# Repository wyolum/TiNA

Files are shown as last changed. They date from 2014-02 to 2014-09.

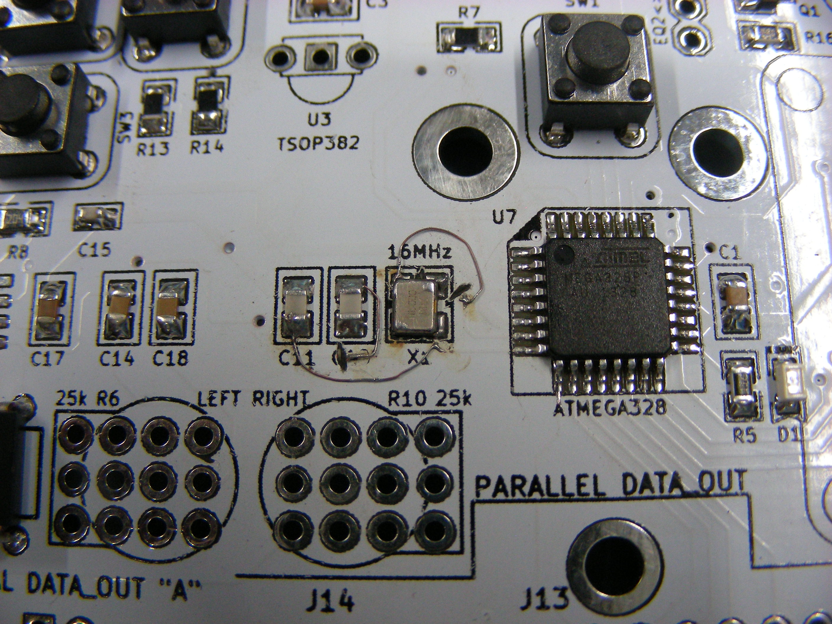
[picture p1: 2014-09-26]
KiCAD/TiNA_Images/DSCN0223.JPG

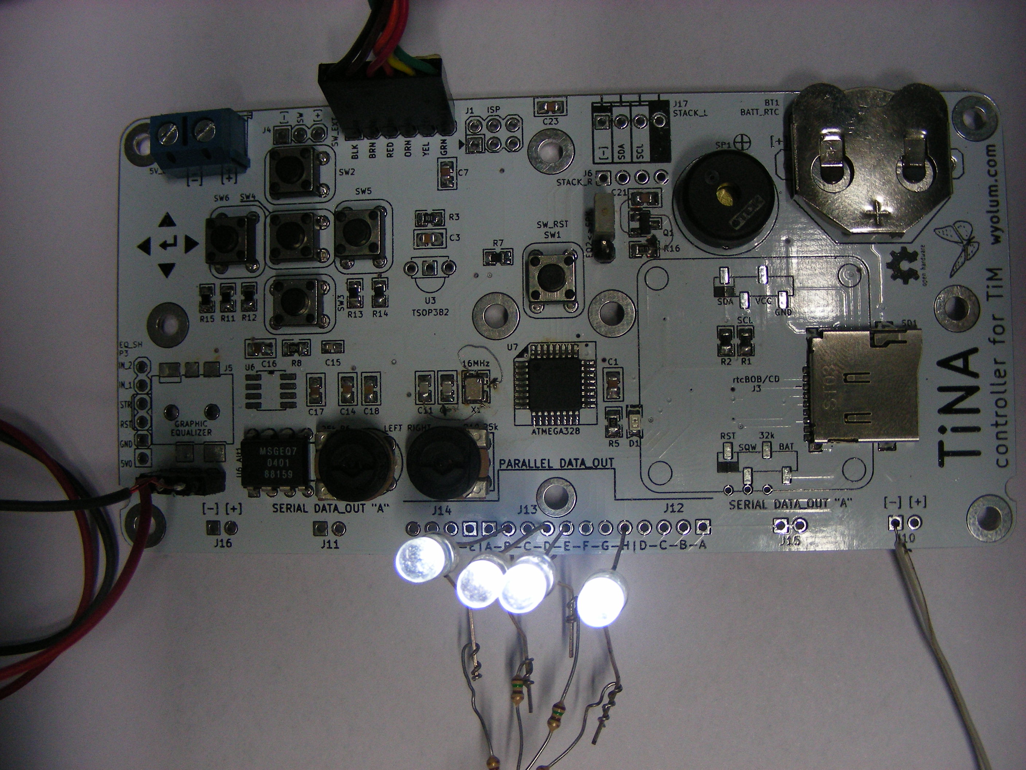
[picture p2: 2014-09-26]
KiCAD/TiNA_Images/DSCN0236.JPG

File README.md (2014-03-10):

TiNA
====

Standalone controller for TIM (The Intelligent Matrix)

To install arduino libraries:
1. download and unzip (or git clone) the files to a local directory
   for example, my this is /home/justin/code/TiNA
2. set your arduino sketchbook path to the arduino subdirectory of your install path by either 
    a. editing your ~/.arduino/preferences.txt (the sketchbook.path variable)
    b. selecting from the "File->Preferences" drop down menu item
    for example, my sketchbook path is /home/justin/code/TiNA/arduino
3. start or restart the Arduino IDE

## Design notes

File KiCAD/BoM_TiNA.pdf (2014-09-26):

TOTAL | 32.26
ref | QTY | DESCRIPTION | value | PACKAGE | Manufacturer | Mfr. P/N | Vendor | Vendor P/N | RATEAMOUNT
BT1 | 1 | | 3003 | 3003K-ND | 0.59 | 0.59
-- | 1 | CR2032 | CR2032 | 0.28 | 0.28
| 6 | 0.1µF | C0805C104K3RACTU | | 0.10 | 0.60
C2 C5 | 2 | 1.0µF | CL21B105KOFNNNE | | 0.10 | 0.20
C3 | 1 | 220nF | CL21B224KBFSFNE | | 0.10 | 0.10
C10 C11 | 2 | 22pF | C0805C220KBRACTU | | 0.08 | 0.17
C24 C25 C26 | 3 | 22uF | C3225X7R1C226M250AC | | 0.84 | 2.52
D1 | 1 | | | | 0.22 | 0.22
Q1 | 1 | MMBT2222 | MMBT2222A | MMBT2222AFSCT-ND | 0.18 | 0.18
| 9 | 10k | RMCF0805JT10K0 | RMCF0805JT10K0CT-ND | 0.03 | 0.27
R3 | 1 | 100E | RMCF0805JT100R | RMCF0805JT100RCT-ND | 0.03 | 0.03
R5 R16 | 2 | 1k5 | RMCF0805JT1K50 | RMCF0805JT1K50CT-ND | 0.03 | 0.06
SD1 | 1 | ? | ? | 0.00
SP1 | 1 | | PS1240P02BT | | 0.73 | 0.73
6 | 1825910-7 | 0.10 | 0.60
U1 | 1 | SOT23-3 | 0.44 | 0.44
U2 | 1 | TXB0104D | TXB0104DR | 1.69 | 1.69

HOLDER BATTERY COIN
20MM DIA THM | BATT_RTC | Coin, 20.0mm | Keystone Electronics | Digikey (http://www.digikey.com/scripts/DkSearch/dksus.dll?x=0&y=0&lang=en&KeyWords=3003K-ND&cur=USD)

BATTERY LITHIUM COIN
3V 20MM | Coin Battery | Panasonic - BSG | | Digikey (http://www.digikey.com/product-detail/en/CR2032/P189-ND/31939?cur=USD) | P189-ND

C1 C7 C9 C21
C22 C23

CAP CER 0.1UF 25V 10%
X7R 0805

0805 (2012
Metric) | Kemet | DigiKey (http://www.digikey.com/product-detail/en/C0805C104K3RACTU/399-1168-1-ND/411443) | 399-1168-1-ND

CAP CER 1UF 16V 10%
X7R 0805

0805 (2012
Metric)
| | Samsung Electro-
| | Mechanics America, Inc | | DigiKey (http://www.digikey.com/product-detail/en/CL21B105KOFNNNE/1276-1026-1-ND/3889112) | 1276-1026-1-ND

CAP CER 0.22UF 50V 10%
X7R 0805

0805 (2012
Metric)
| | Samsung Electro-
| | Mechanics America, Inc | | DigiKey (http://www.digikey.com/product-detail/en/CL21B224KBFSFNE/1276-2948-1-ND/3891034) | 1276-2948-1-ND

CAP CER 22PF 630V 10%
X7R 0805

0805 (2012
Metric) | Kemet | DigiKey (http://www.digikey.com/product-detail/en/C0805C220KBRACTU/399-5568-2-ND/2033869) | 399-5568-2-ND

CAP CER 22UF 16V 20%
X7R 1210

1210 (3225
Metric) | TDK Corporation | DigiKey (http://www.digikey.com/product-detail/en/C3225X7R1C226M250AC/445-3955-1-ND/1944442) | 445-3955-1-ND
LED, indicator, BLINK | LED | 2-SMD, J-Lead | OSRAM Opto
| | Semiconductors Inc | LG M67K-H1J2-24-Z | DigiKey (http://www.digikey.com/product-detail/en/LG%20M67K-H1J2-24-Z/475-2730-1-ND/1938897?cur=USD) | 475-2730-1-ND

TRANSISTOR GP NPN
AMP SOT-23 | SOT-23-3 | Fairchild Semiconductor | DigiKey (http://www.digikey.com/product-detail/en/MMBT2222A/MMBT2222AFSCT-ND/458969)

R1 R2 R7 R9 R11
R12 R13 R14
R15

RES 10K OHM 1/8W 5%
0805

0805 (2012
Metric) | Stackpole Electronics Inc | DigiKey (http://www.digikey.com/product-detail/en/RMCF0805JT10K0/RMCF0805JT10K0CT-ND/1942577)

RES 100 OHM 1/8W 5%
0805

0805 (2012
Metric) | Stackpole Electronics Inc | DigiKey (http://www.digikey.com/product-detail/en/RMCF0805JT100R/RMCF0805JT100RCT-ND/1942539)

RES 1.5K OHM 1/8W 5%
0805

0805 (2012
Metric) | Stackpole Electronics Inc | DigiKey (http://www.digikey.com/product-detail/en/RMCF0805JT1K50/RMCF0805JT1K50CT-ND/1942560)
Micro SD Card Socket | SD_CARD_MICR
| O | | | seeed | ST-SD-006A

BUZZER PIEZO 4KHZ
12.2MM PC MNT | Speaker

Circular -
12.20mm Dia x
6.50mm H
| | TDK Corporation | | DigiKey (http://www.digikey.com/product-detail/en/PS1240P02BT/445-2525-1-ND/935930) | 445-2525-1-ND

SW1 SW2 SW3
SW4 SW5 SW6
SWITCH TACTILE SPST- NO 0.05A 12V | SW_RST SW_UP
| SW_DN SW_OK
| SW_LT SW_RT

6.00mm x
6.00mm | TE Connectivity | DigiKey (http://www.digikey.com/product-detail/en/1825910-7/450-1804-ND/1731414) | 450-1804-ND
IC REG LDO 3.3V 0.25A | LDO 3V3 | Microchip Technology | MCP1700T-3302E/TT | DigiKey (http://www.digikey.com/product-search/en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) | MCP1700T3302ETTCT-
| | | | | ND
(or U1_Alt1) | (or SOT-89-3) | (or MCP1700T-
| | | 3302E/MB) | | (or
| | | | | MCP1700T3302EMBCT-
| | | | | ND)

IC VOLT-LEVEL
TRANSLATOR 14-SOIC

14-SOIC (0.154",
| | 3.90mm Width) Texas Instruments | | DigiKey (http://www.digikey.com/product-detail/en/TXB0104DR/296-21928-1-ND/1629281) | 296-21928-1-ND

U4 | 1 | DS3231N | DS3231S# | | 8.82 | 8.82
U7 | 1 | ATMEGA328P | ATMEGA328P-AU | ATMEGA328P-AU-ND | 3.12 | 3.12
X1 | 1 | 16MHz | | SER3628CT-ND | 0.63 | 0.63
J1 | 1 | PREC003DAAN-RC | 0.25 | 0.25
1 | PREC040SAAN-RC | 0.51 | 0.51
J8 | 1 | OSTTA024163 | 0.42 | 0.42
J5 | 1 | CP1-3515SJPICT-ND | 1.45 | 1.45
U3 | 1 | TSOP382 | | TSOP38238 | | 0.91 | 0.91
U6 | 1 | MSGEQ7 | SO8 | MSGEQ7 | MSGEQ7 | 4.95 | 4.95
C14 C18 | 2 | 10nF | CL21B103JBANNNC | 0.11 | 0.22
C15 | 1 | 33pF | 0603YC330JAT2A | 0.18 | 0.18
C16 C17 | 2 | 0.1µF | C0805C104K3RACTU | 0.10 | 0.20
R6 R10 | 2 | 25k | 262UR253B | 262UR253B-ND | 0.69 | 1.38
IC RTC W/TCXO 16-SOIC | 16-SOIC (0.295",
| 7.50mm Width) | Maxim Integrated
Products | DigiKey (http://goo.gl/gg9GS) | DS3231S#-ND

IC MCU 8BIT 32KB FLASH
32TQFP | 32-TQFP | Atmel | DigiKey (http://www.digikey.com/product-detail/en/ATMEGA328P-AU/ATMEGA328P-AU-ND/1832260)
CRYSTAL 16MHZ 9PF SMD | 4-SMD, No Lead
(DFN, LCC) | EPSON | TSX-3225 16.0000MF09Z-
AC3 | DigiKey (http://www.digikey.com/product-detail/en/TSX-3225%2016.0000MF09Z-AC3/SER3628CT-ND/1802879)

DO NOT
POPULATE
CONN HEADER .100"
DUAL STR 6POS | ISP | Dual row, 0.1” | Sullins Connector
Solutions | DigiKey (http://www.digikey.com/product-detail/en/PREC003DAAN-RC/S2012EC-03-ND/2774891) | S2012EC-03-ND

J2 J4 J6 J10 J11
J12 J13 J14 J15
J16 J17 J18

CONN HEADER .100"
SNGL STR 40POS

PWR_1 SER_1
PAR_1 PAR_2
PAR_3 SER_2
PWR_2 STACK_R
EqIn_EXT FTDI
SW_EXT
STACK_L

Single row, 0.1” Sullins Connector
Solutions | DigiKey (http://www.digikey.com/product-detail/en/PREC040SAAN-RC/S1012EC-40-ND/2774814) | S1012EC-40-ND

TERM BLOCK 5.08MM

VERT 2POS PCB | 5V_EXT | Through Hole,
0.2” | On Shore Technology Inc | DigiKey (http://www.digikey.com/product-detail/en/OSTTA024163/ED2580-ND/614529) | ED2580-ND

CONN JACK STEREO
5POS 3.5MM SMD

JACK_3.5MM_5P
IN

3.50mm (0.141",
1/8", Mini Plug) -
Headphone
CUI Inc | SJ1-3515-SMT-TR-PI | DigiKey (http://www.digikey.com/product-detail/en/SJ1-3515-SMT-TR-PI/CP1-3515SJPICT-ND/2296003)

IC IR RCVR MOD 38KHZ

DOME AXIAL | Side View | Vishay Semiconductor
| Opto Division | DigiKey (http://www.digikey.com/product-detail/en/TSOP38238/751-1227-ND/1681362) | 751-1227-ND

IC seven band graphic
equalizer | MSI | Sparkfun (https://www.sparkfun.com/products/10468)
(or U6_Alt1) | DIP-8
CAP CER 10000PF 50V
5% X7R 0805
0805 (2012 Metric) | Samsung Electro-
| Mechanics America, Inc | DigiKey (http://www.digikey.com/product-detail/en/CL21B103JBANNNC/1276-1245-1-ND/3889331) | 1276-1245-1-ND

CAP CER 33PF 16V 5%
X7R 0603

0603 (1608
Metric) | AVX Corporation | DigiKey (http://www.digikey.com/product-detail/en/0603YC330JAT2A/478-6211-1-ND/2391410) | 478-6211-1-ND

CAP CER 0.1UF 25V 10%
X7R 0805

0805 (2012
Metric) | Kemet | DigiKey (http://www.digikey.com/product-detail/en/C0805C104K3RACTU/399-1168-1-ND/411443) | 399-1168-1-ND

TRIMMER 25K OHM
0.15W TH

Square - 0.370" L
x 0.368" W x
0.213" H
(9.40mm x
9.35mm x
5.40mm)
CTS Electrocomponents | DigiKey (http://www.digikey.com/product-detail/en/262UR253B/262UR253B-ND/3063)

R8 | 1 | 200k | RMCF0805JT200K | RMCF0805JT200KCT-ND | 0.03 | 0.03
P2 P3 | 1 | | PREC040SAAN-RC | | 0.51 | 0.51

10.00

C4 | 1 | 10uF | CL31B106KOHNNNE | | 0.29 | 0.29
C6 C13 | 2 | 0.1µF | C0805C104K3RACTU | | 0.10 | 0.20
C8 | 1 | 3.3nF X7R | C0805C332K5RACTU | | 0.10 | 0.10
C12 | 1 | 22uF | C3225X7R1C226M250AC | | 0.84 | 0.84
C19 C20 | 2 | 100uF | UWT1V101MCL1GS | | 0.48 | 0.96
D2 | 1 | | GBU4M-BP | GBU4M-BPMS-ND | 0.88 | 0.88
J7 J9 | 2 | | OSTTA024163 | | 0.42 | 0.84
L1 | 1 | 2.2uH | XFL4020-222MEB | 994-XFL4020-222MEB | 2.13 | 2.13
R4 | 1 | 100k | RMCF0805JT100K | RMCF0805JT100KCT-ND | 0.03 | 0.03
U5 | 1 | TPS62133 | TPS62133RGTT | | 3.73 | 3.73

RES 200K OHM 1/8W 5%
0805

0805 (2012
Metric) | Stackpole Electronics Inc | DigiKey (http://www.digikey.com/product-detail/en/RMCF0805JT200K/RMCF0805JT200KCT-ND/1942595)

CONN HEADER .100"
SNGL STR 10POS

SPK<>EQ2

EQ_SH | Single row, 0.1” Sullins Connector
Solutions | DigiKey (http://www.digikey.com/product-detail/en/PREC040SAAN-RC/S1012EC-40-ND/2774814) | S1012EC-40-ND
POWER SUPPLY | TOTAL

CAP CER 10UF 16V 10%
X7R 1206

1206 (3216
Metric)

Samsung Electro-
Mechanics America, Inc | DigiKey (http://www.digikey.com/product-detail/en/CL31B106KOHNNNE/1276-1082-1-ND/3889168) | 1276-1082-1-ND

CAP CER 0.1UF 25V 10%
X7R 0805

0805 (2012
Metric) | Kemet | DigiKey (http://www.digikey.com/product-detail/en/C0805C104K3RACTU/399-1168-1-ND/411443) | 399-1168-1-ND

CAP CER 3300PF 50V
10% X7R 0805

0805 (2012
Metric) | Kemet | DigiKey (http://www.digikey.com/product-detail/en/C0805C332K5RACTU/399-1153-1-ND/411428) | 399-1153-1-ND

CAP CER 22UF 16V 20%
X7R 1210

1210 (3225
Metric) | TDK Corporation | DigiKey (http://www.digikey.com/product-detail/en/C3225X7R1C226M250AC/445-3955-1-ND/1944442) | 445-3955-1-ND

CAP ALUM 100UF 35V
20% SMD

Radial, Can -
SMD | Nichicon | DigiKey (http://www.digikey.com/product-detail/en/UWT1V101MCL1GS/493-2203-1-ND/590178) | 493-2203-1-ND

RECT BRIDGE GPP 4A
1000V GBU | Bridge | Through Hole | Micro Commercial Co | DigiKey (http://www.digikey.com/product-detail/en/GBU4M-BP/GBU4M-BPMS-ND/1140594)

TERM BLOCK 5.08MM

VERT 2POS PCB | V_IN 5V_EXT | Through Hole,
0.2” | On Shore Technology Inc | DigiKey (http://www.digikey.com/product-detail/en/OSTTA024163/ED2580-ND/614529) | ED2580-ND

Power Inductor 2.2 uH 20
% 8 A

4.3 mm W x 4.3
mm L x 2.1 mm H | Coilcraft | Mouser (http://in.mouser.com/ProductDetail/Coilcraft/XFL4020-222MEB/?qs=VJjuEbE9QBO2bwonVBK1EA==)

RES 100K OHM 1/8W 5%
0805

0805 (2012
Metric) | Stackpole Electronics Inc | DigiKey (http://www.digikey.com/product-detail/en/RMCF0805JT100K/RMCF0805JT100KCT-ND/1942592)

IC REG BUCK SYNC 5V 3A
16QFN

16-VFQFN
Exposed Pad | Texas Instruments | DigiKey (http://www.digikey.com/product-detail/en/TPS62133RGTT/296-30225-1-ND/2982139) | 296-30225-1-ND

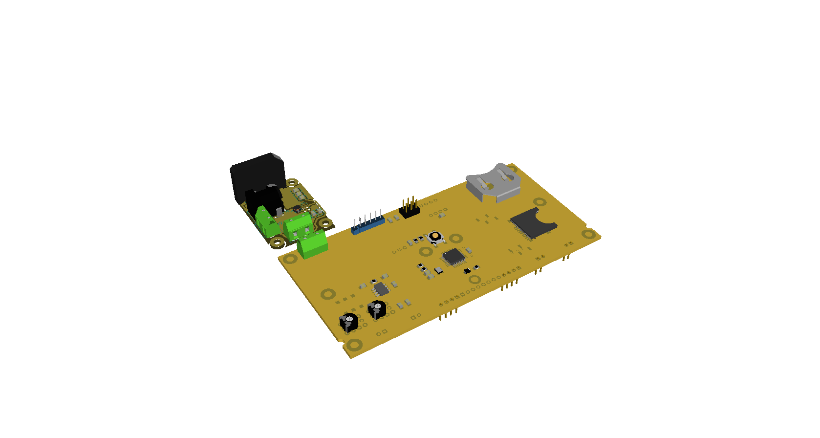
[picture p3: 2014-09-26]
KiCAD/TiNA_Images/TiNA_01.png

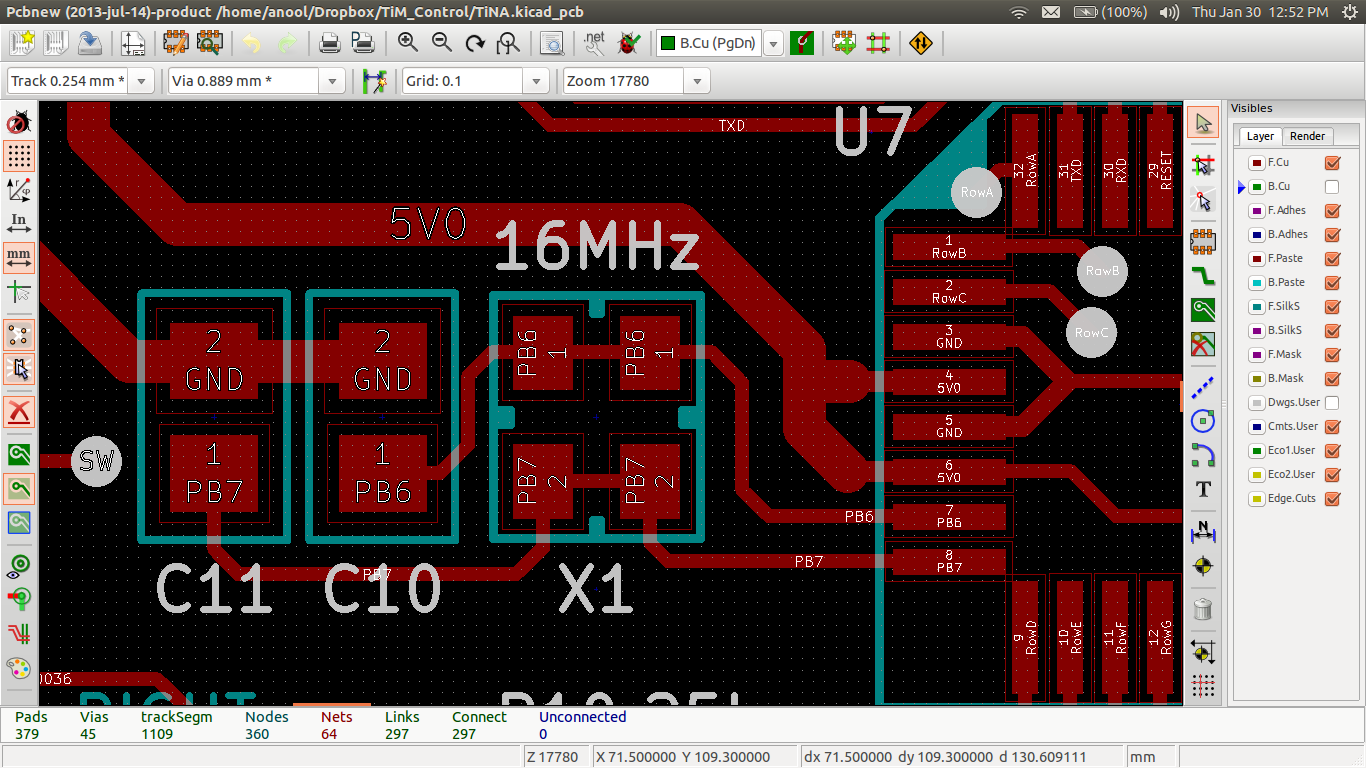
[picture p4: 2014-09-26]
KiCAD/TiNA_Images/TiNA_Mod_BEFORE.png

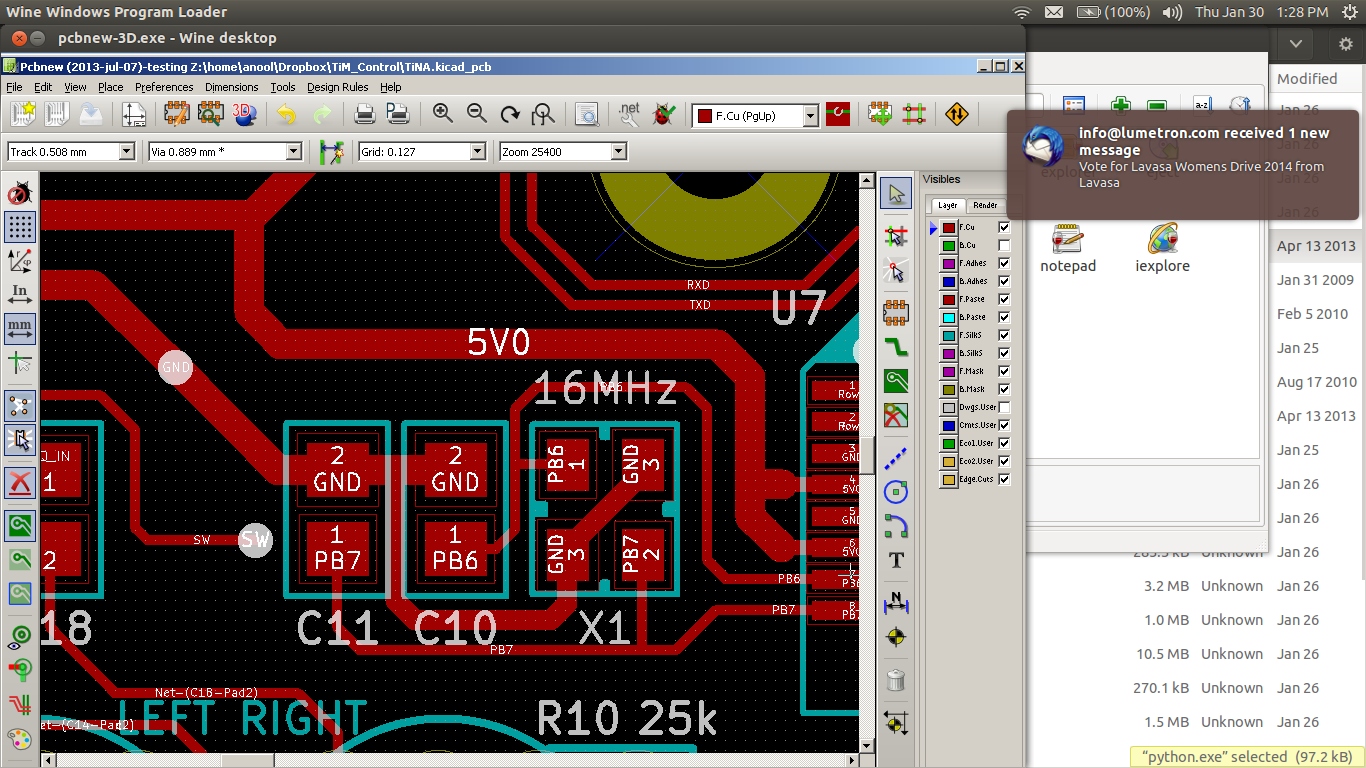
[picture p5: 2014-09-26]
KiCAD/TiNA_Images/Screenshot from 2014-01-30 13:28:08.png

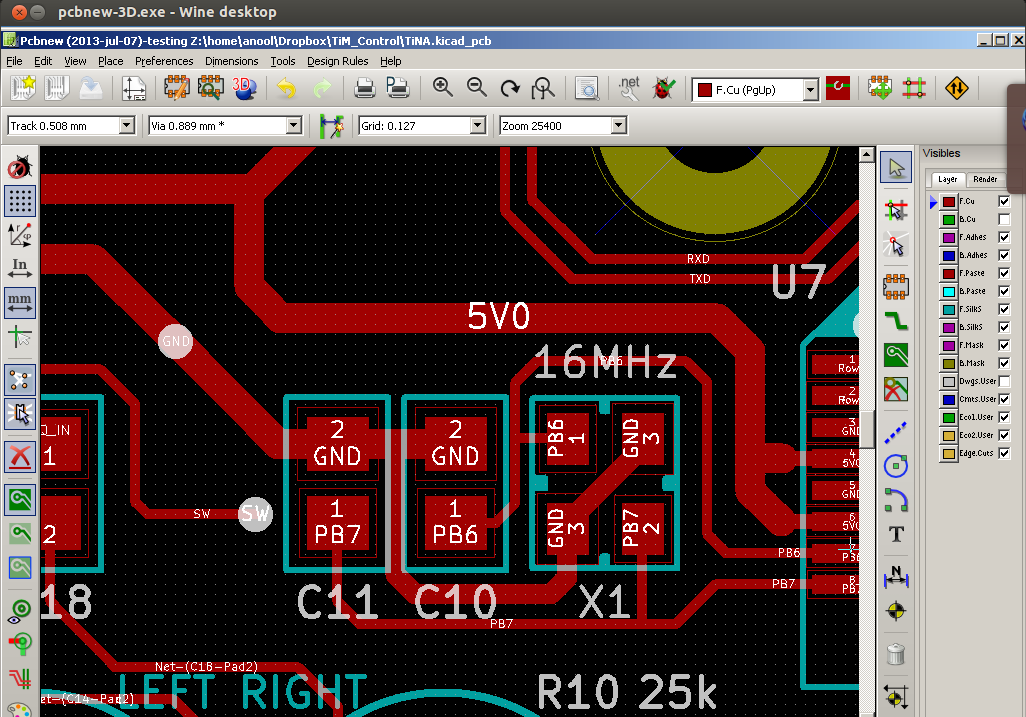
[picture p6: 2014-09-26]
KiCAD/TiNA_Images/TiNA_Mod_AFTER.png

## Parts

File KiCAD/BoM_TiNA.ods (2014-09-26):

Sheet: Final_BoM
 |  |  |  |  |  |  |  |  | TOTAL | 29.66
ref | QTY | DESCRIPTION | value | PACKAGE | Manufacturer | Mfr. P/N | Vendor | Vendor P/N | RATE | AMOUNT
BT1 | 1 | HOLDER BATTERY COIN 20MM DIA THM | BATT_RTC | Coin, 20.0mm | Keystone Electronics | 3003 | Digikey (http://www.digikey.com/scripts/DkSearch/dksus.dll?x=0&y=0&lang=en&KeyWords=3003K-ND&cur=USD) | 3003K-ND | 0.59 | 0.59
-- | 1 | BATTERY LITHIUM COIN 3V 20MM | Coin Battery | CR2032 | Panasonic - BSG | CR2032 | Digikey (http://www.digikey.com/product-detail/en/CR2032/P189-ND/31939?cur=USD) | P189-ND | 0.28 | 0.28
C1 C7 C9 C21 C22 C23 | 6 | CAP CER 0.1UF 25V 10% X7R 0805 | 0.1µF | 0805 (2012 Metric) | Kemet | C0805C104K3RACTU | DigiKey (http://www.digikey.com/product-detail/en/C0805C104K3RACTU/399-1168-1-ND/411443) | 399-1168-1-ND | 0.10 | 0.60
C2 C5 | 2 | CAP CER 1UF 16V 10% X7R 0805 | 1.0µF | 0805 (2012 Metric) | Samsung Electro-Mechanics America, Inc | CL21B105KOFNNNE | DigiKey (http://www.digikey.com/product-detail/en/CL21B105KOFNNNE/1276-1026-1-ND/3889112) | 1276-1026-1-ND | 0.10 | 0.20
C3 | 1 | CAP CER 0.22UF 50V 10% X7R 0805 | 220nF | 0805 (2012 Metric) | Samsung Electro-Mechanics America, Inc | CL21B224KBFSFNE | DigiKey (http://www.digikey.com/product-detail/en/CL21B224KBFSFNE/1276-2948-1-ND/3891034) | 1276-2948-1-ND | 0.10 | 0.10
C10 C11 | 2 | CAP CER 22PF 630V 10% X7R 0805 | 22pF | 0805 (2012 Metric) | Kemet | C0805C220KBRACTU | DigiKey (http://www.digikey.com/product-detail/en/C0805C220KBRACTU/399-5568-2-ND/2033869) | 399-5568-2-ND | 0.08 | 0.17
C14 C18 | 2 | CAP CER 10000PF 50V 5% X7R 0805 | 10nF | 0805 (2012 Metric) | Samsung Electro-Mechanics America, Inc | CL21B103JBANNNC | DigiKey (http://www.digikey.com/product-detail/en/CL21B103JBANNNC/1276-1245-1-ND/3889331) | 1276-1245-1-ND | 0.11 | 0.22
C15 | 1 | CAP CER 33PF 16V 5% X7R 0603 | 33pF | 0603 (1608 Metric) | AVX Corporation | 0603YC330JAT2A | DigiKey (http://www.digikey.com/product-detail/en/0603YC330JAT2A/478-6211-1-ND/2391410) | 478-6211-1-ND | 0.18 | 0.18
C16 C17 | 2 | CAP CER 0.1UF 25V 10% X7R 0805 | 0.1µF | 0805 (2012 Metric) | Kemet | C0805C104K3RACTU | DigiKey (http://www.digikey.com/product-detail/en/C0805C104K3RACTU/399-1168-1-ND/411443) | 399-1168-1-ND | 0.10 | 0.20
C24 C25 C26 | 3 | CAP CER 22UF 16V 20% X7R 1210 | 22uF | 1210 (3225 Metric) | TDK Corporation | C3225X7R1C226M250AC | DigiKey (http://www.digikey.com/product-detail/en/C3225X7R1C226M250AC/445-3955-1-ND/1944442) | 445-3955-1-ND | 0.84 | 2.52
D1 | 1 | LED, indicator, BLINK | LED | 2-SMD, J-Lead | OSRAM Opto Semiconductors Inc | LG M67K-H1J2-24-Z | DigiKey (http://www.digikey.com/product-detail/en/LG%20M67K-H1J2-24-Z/475-2730-1-ND/1938897?cur=USD) | 475-2730-1-ND | 0.22 | 0.22
J5 | 1 | CONN JACK STEREO 5POS 3.5MM SMD | JACK_3.5MM_5PIN | 3.50mm (0.141", 1/8", Mini Plug) - Headphone | CUI Inc | SJ1-3515-SMT-TR-PI | DigiKey (http://www.digikey.com/product-detail/en/SJ1-3515-SMT-TR-PI/CP1-3515SJPICT-ND/2296003) | CP1-3515SJPICT-ND | 1.45 | 1.45
Q1 | 1 | TRANSISTOR GP NPN AMP SOT-23 | MMBT2222 | SOT-23-3 | Fairchild Semiconductor | MMBT2222A | DigiKey (http://www.digikey.com/product-detail/en/MMBT2222A/MMBT2222AFSCT-ND/458969) | MMBT2222AFSCT-ND | 0.18 | 0.18
R1 R2 R7 R9 R11 R12 R13 R14 R15 | 9 | RES 10K OHM 1/8W 5% 0805 | 10k | 0805 (2012 Metric) | Stackpole Electronics Inc | RMCF0805JT10K0 | DigiKey (http://www.digikey.com/product-detail/en/RMCF0805JT10K0/RMCF0805JT10K0CT-ND/1942577) | RMCF0805JT10K0CT-ND | 0.03 | 0.27
R3 | 1 | RES 100 OHM 1/8W 5% 0805 | 100E | 0805 (2012 Metric) | Stackpole Electronics Inc | RMCF0805JT100R | DigiKey (http://www.digikey.com/product-detail/en/RMCF0805JT100R/RMCF0805JT100RCT-ND/1942539) | RMCF0805JT100RCT-ND | 0.03 | 0.03
R5 R16 | 2 | RES 1.5K OHM 1/8W 5% 0805 | 1k5 | 0805 (2012 Metric) | Stackpole Electronics Inc | RMCF0805JT1K50 | DigiKey (http://www.digikey.com/product-detail/en/RMCF0805JT1K50/RMCF0805JT1K50CT-ND/1942560) | RMCF0805JT1K50CT-ND | 0.03 | 0.06
R6 R10 | 2 | TRIMMER 25K OHM 0.15W TH | 25k | Square - 0.370" L x 0.368" W x 0.213" H (9.40mm x 9.35mm x 5.40mm) | CTS Electrocomponents | 262UR253B | DigiKey (http://www.digikey.com/product-detail/en/262UR253B/262UR253B-ND/3063) | 262UR253B-ND | 0.69 | 1.38
R8 | 1 | RES 200K OHM 1/8W 5% 0805 | 200k | 0805 (2012 Metric) | Stackpole Electronics Inc | RMCF0805JT200K | DigiKey (http://www.digikey.com/product-detail/en/RMCF0805JT200K/RMCF0805JT200KCT-ND/1942595) | RMCF0805JT200KCT-ND | 0.03 | 0.03
SD1 | 1 | Micro SD Card Socket | SD_CARD_MICRO |  | ? | ? | seeed | ST-SD-006A |  | 0.00
SP1 | 1 | BUZZER PIEZO 4KHZ 12.2MM PC MNT | Speaker | Circular - 12.20mm Dia x 6.50mm H | TDK Corporation | PS1240P02BT | DigiKey (http://www.digikey.com/product-detail/en/PS1240P02BT/445-2525-1-ND/935930) | 445-2525-1-ND | 0.73 | 0.73
SW1 SW2 SW3 SW4 SW5 SW6 | 6 | SWITCH TACTILE SPST-NO 0.05A 12V | SW_RST SW_UP SW_DN SW_OK SW_LT SW_RT | 6.00mm x 6.00mm | TE Connectivity | 1825910-7 | DigiKey (http://www.digikey.com/product-detail/en/1825910-7/450-1804-ND/1731414) | 450-1804-ND | 0.10 | 0.60
U1 | 1 | IC REG LDO 3.3V 0.25A | LDO 3V3 | SOT23-3 | Microchip Technology | MCP1700T-3302E/TT | DigiKey (http://www.digikey.com/product-search/en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) | MCP1700T3302ETTCT-ND | 0.44 | 0.44
(or U1_Alt1) |  |  |  | (or SOT-89-3) |  | (or MCP1700T-3302E/MB) |  | (or MCP1700T3302EMBCT-ND)
U2 | 1 | IC VOLT-LEVEL TRANSLATOR 14-SOIC | TXB0104D | 14-SOIC (0.154", 3.90mm Width) | Texas Instruments | TXB0104DR | DigiKey (http://www.digikey.com/product-detail/en/TXB0104DR/296-21928-1-ND/1629281) | 296-21928-1-ND | 1.69 | 1.69
U4 | 1 | IC RTC W/TCXO 16-SOIC | DS3231N | 16-SOIC (0.295", 7.50mm Width) | Maxim Integrated Products | DS3231S# | DigiKey (http://goo.gl/gg9GS) | DS3231S#-ND | 8.82 | 8.82
U6 | 1 | IC seven band graphic equalizer | MSGEQ7 | SO8 | MSI | MSGEQ7 | Sparkfun (https://www.sparkfun.com/products/10468) | MSGEQ7 | 4.95 | 4.95
(or U6_Alt1) |  |  |  | DIP-8
U7 | 1 | IC MCU 8BIT 32KB FLASH 32TQFP | ATMEGA328P | 32-TQFP | Atmel | ATMEGA328P-AU | DigiKey (http://www.digikey.com/product-detail/en/ATMEGA328P-AU/ATMEGA328P-AU-ND/1832260) | ATMEGA328P-AU-ND | 3.12 | 3.12
X1 | 1 | CRYSTAL 16MHZ 9PF SMD | 16MHz | 4-SMD, No Lead (DFN, LCC) | EPSON | TSX-3225 16.0000MF09Z-AC3 | DigiKey (http://www.digikey.com/product-detail/en/TSX-3225%2016.0000MF09Z-AC3/SER3628CT-ND/1802879) | SER3628CT-ND | 0.63 | 0.63
POWER SUPPLY |  |  |  |  |  |  |  |  | TOTAL | 10.00
C4 | 1 | CAP CER 10UF 16V 10% X7R 1206 | 10uF | 1206 (3216 Metric) | Samsung Electro-Mechanics America, Inc | CL31B106KOHNNNE | DigiKey (http://www.digikey.com/product-detail/en/CL31B106KOHNNNE/1276-1082-1-ND/3889168) | 1276-1082-1-ND | 0.29 | 0.29
C6 C13 | 2 | CAP CER 0.1UF 25V 10% X7R 0805 | 0.1µF | 0805 (2012 Metric) | Kemet | C0805C104K3RACTU | DigiKey (http://www.digikey.com/product-detail/en/C0805C104K3RACTU/399-1168-1-ND/411443) | 399-1168-1-ND | 0.10 | 0.20
C8 | 1 | CAP CER 3300PF 50V 10% X7R 0805 | 3.3nF X7R | 0805 (2012 Metric) | Kemet | C0805C332K5RACTU | DigiKey (http://www.digikey.com/product-detail/en/C0805C332K5RACTU/399-1153-1-ND/411428) | 399-1153-1-ND | 0.10 | 0.10
C12 | 1 | CAP CER 22UF 16V 20% X7R 1210 | 22uF | 1210 (3225 Metric) | TDK Corporation | C3225X7R1C226M250AC | DigiKey (http://www.digikey.com/product-detail/en/C3225X7R1C226M250AC/445-3955-1-ND/1944442) | 445-3955-1-ND | 0.84 | 0.84
C19 C20 | 2 | CAP ALUM 100UF 35V 20% SMD | 100uF | Radial, Can - SMD | Nichicon | UWT1V101MCL1GS | DigiKey (http://www.digikey.com/product-detail/en/UWT1V101MCL1GS/493-2203-1-ND/590178) | 493-2203-1-ND | 0.48 | 0.96
D2 | 1 | RECT BRIDGE GPP 4A 1000V GBU | Bridge | Through Hole | Micro Commercial Co | GBU4M-BP | DigiKey (http://www.digikey.com/product-detail/en/GBU4M-BP/GBU4M-BPMS-ND/1140594) | GBU4M-BPMS-ND | 0.88 | 0.88
J7 J9 | 2 | TERM BLOCK 5.08MM VERT 2POS PCB | V_IN 5V_EXT | Through Hole, 0.2” | On Shore Technology Inc | OSTTA024163 | DigiKey (http://www.digikey.com/product-detail/en/OSTTA024163/ED2580-ND/614529) | ED2580-ND | 0.42 | 0.84
L1 | 1 | Power Inductor 2.2 uH 20 % 8 A | 2.2uH | 4.3 mm W x 4.3 mm L x 2.1 mm H | Coilcraft | XFL4020-222MEB | Mouser (http://in.mouser.com/ProductDetail/Coilcraft/XFL4020-222MEB/?qs=VJjuEbE9QBO2bwonVBK1EA==) | 994-XFL4020-222MEB | 2.13 | 2.13
R4 | 1 | RES 100K OHM 1/8W 5% 0805 | 100k | 0805 (2012 Metric) | Stackpole Electronics Inc | RMCF0805JT100K | DigiKey (http://www.digikey.com/product-detail/en/RMCF0805JT100K/RMCF0805JT100KCT-ND/1942592) | RMCF0805JT100KCT-ND | 0.03 | 0.03
U5 | 1 | IC REG BUCK SYNC 5V 3A 16QFN | TPS62133 | 16-VFQFN Exposed Pad | Texas Instruments | TPS62133RGTT | DigiKey (http://www.digikey.com/product-detail/en/TPS62133RGTT/296-30225-1-ND/2982139) | 296-30225-1-ND | 3.73 | 3.73
DO NOT POPULATE |  | (PLEASE ADD AS KIT PARTS)
J1 | 1 | CONN HEADER .100" DUAL STR 6POS | ISP | Dual row, 0.1” | Sullins Connector Solutions | PREC003DAAN-RC | DigiKey (http://www.digikey.com/product-detail/en/PREC003DAAN-RC/S2012EC-03-ND/2774891) | S2012EC-03-ND | 0.25 | 0.25
J2 J4 J6 J10 J11 J12 J13 J14 J15 J16 J17 J18 | 1 | CONN HEADER .100" SNGL STR 40POS | PWR_1 SER_1 PAR_1 PAR_2 PAR_3 SER_2 PWR_2 STACK_R EqIn_EXT FTDI SW_EXT STACK_L | Single row, 0.1” | Sullins Connector Solutions | PREC040SAAN-RC | DigiKey (http://www.digikey.com/product-detail/en/PREC040SAAN-RC/S1012EC-40-ND/2774814) | S1012EC-40-ND | 0.51 | 0.51
J8 | 1 | TERM BLOCK 5.08MM VERT 2POS PCB | 5V_EXT | Through Hole, 0.2” | On Shore Technology Inc | OSTTA024163 | DigiKey (http://www.digikey.com/product-detail/en/OSTTA024163/ED2580-ND/614529) | ED2580-ND | 0.42 | 0.42
U3 | 1 | IC IR RCVR MOD 38KHZ DOME AXIAL | TSOP382 | Side View | Vishay Semiconductor Opto Division | TSOP38238 | DigiKey (http://www.digikey.com/product-detail/en/TSOP38238/751-1227-ND/1681362) | 751-1227-ND | 0.91 | 0.91
P2 P3 | 1 | CONN HEADER .100" SNGL STR 10POS | SPK<>EQ2 EQ_SH | Single row, 0.1” | Sullins Connector Solutions | PREC040SAAN-RC | DigiKey (http://www.digikey.com/product-detail/en/PREC040SAAN-RC/S1012EC-40-ND/2774814) | S1012EC-40-ND | 0.51 | 0.51

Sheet: BoM_SCH
Designator | Designation | Quantity | Package
BT1 | BATT_RTC | 1 | CR2032
C1 C7 C9 C21 C22 C23 | 100nF | 6 | c_0805
C10 C11 | 22pF | 2 | c_0805
C24 C25 C26 | 22uF X7R | 3 | c_1210
C2 C5 | 1uF | 2 | c_0805
C3 | 220nF | 1 | c_0805
D1 | LED | 1 | d_0805
Q1 | MMBT2222 | 1 | SOT23-3
R1 R2 R7 R9 R11 R12 R13 R14 R15 | 10k | 9 | r_0805
R3 | 100E | 1 | r_0805
R5 R16 | 1k5 | 2 | r_0805
SD1 | SD_CARD_MICRO | 1 | SD_Micro_seeed
SP1 | SPEAKER | 1 | Speaker_2
SW1 | SW_RST | 1 | SW-PB
SW2 | SW_UP | 1 | SW-PB
SW3 | SW_DN | 1 | SW-PB
SW4 | SW_OK | 1 | SW-PB
SW5 | SW_LT | 1 | SW-PB
SW6 | SW_RT | 1 | SW-PB
U1 | MCP1700T-3V3 SOT23-3 | 1 | SOT23-3
U1_Alt1 | MCP1700T-3V3 SOT89 | 1 | SOT89
U2 | TXB0104D | 1 | TXB0104D
U4 | DS3231N | 1 | DS3231
U7 | ATMEGA328 | 1 | TQFP32
X1 | 16MHz | 1 | Xtal_SMD2
DNP
B2 B3 B15 | I/O | 3 | I/O
J1 | ISP | 1 | ISP
J2 | FTDI | 1 | PIN_ARRAY-6X1
J3 | rtcBOB/CD | 1 | rtcBOB
J4 | SW_EXT | 1 | PIN_ARRAY_3x1
J5 | JACK_3.5MM_5PIN | 1 | Jack_3.5mm_SJ1-3513
J6 | STACK_L | 1 | STACK-L
J8 | 5V_EXT | 1 | bornier2
J10 | PWR_1 | 1 | pin_strip_2
J11 | SER_1 | 1 | pin_strip_2
J12 | PAR_1 | 1 | PIN_ARRAY_4x1
J13 | PAR_2 | 1 | SIL-8
J14 | PAR_3 | 1 | PIN_ARRAY_4x1
J15 | SER_2 | 1 | pin_strip_2
J16 | PWR_2 | 1 | pin_strip_2
J17 | STACK_R | 1 | STACK-R
J18 | EqIn_EXT | 1 | PIN_ARRAY_3x1
P1 | V_IN | 1 | JACK_ALIM
SC1 SC2 SC3 SC4 SC5 SC6 SC7 SC8 SC9 SC10 SC11 SC12 | SCREW | 12 | vite_3mm
U3 | TSOP382 | 1 | TSOP382
P2 | SPK<>EQ2 | 1 | PIN_ARRAY_3x1
P3 | EQ_SH | 1 | PIN_ARRAY-6X1
U6 | MSGEQ7 | 1 | SO8E
U6_Alt1 | MSGEQ7_DIP | 1 | DIP-8__300
R6 R10 | 25k | 2 | Pot-Var2
R8 | 200k | 1 | r_0805
C14 C18 | 10nF | 2 | c_0805
C15 | 33pF | 1 | c_0603
C16 C17 | 100nF | 2 | c_0805
POWER SUPPLY
C4 | 10uF X7R | 1 | c_1206
C6 C13 | 100nF | 2 | c_0805
C8 | 3.3nF | 1 | c_0805
C12 | 22uF X7R | 1 | c_1210
C19 C20 | 100uF | 2 | C_ELCO_SMD
D2 | BRIDGE | 1 | Bridge
J7 | V_IN | 1 | bornier2
J9 | 5V_EXT | 1 | bornier2
L1 | 2u2H,3.0A | 1 | Inductor_SMD3
R4 | 100k | 1 | r_0805
U5 | TPS62133 | 1 | TPS62132

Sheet: BoM_PCB
Designator | Designation | Quantity | Package
BT1 | BATT_RTC | 1 | CR2032
C1 C7 C9 C21 C22 C23 | 100nF | 6 | c_0805
C10 C11 | 22pF | 2 | c_0805
C24 C26 C25 | 22uF X7R | 3 | c_1210
C2 C5 | 1uF | 2 | c_0805
C3 | 220nF | 1 | c_0805
D1 | LED | 1 | d_0805
Q1 | MMBT2222 | 1 | SOT23-3
R9 R7 R2 R1 R11 R12 R13 R14 R15 | 10k | 9 | r_0805
R3 | 100E | 1 | r_0805
R5 R16 | 1k5 | 2 | r_0805
SD1 | SD_CARD_MICRO | 1 | SD_Micro_seeed
SP1 | SPEAKER | 1 | Speaker_2
SW1 | SW_RST | 1 | SW-PB
SW2 | SW_UP | 1 | SW-PB
SW3 | SW_DN | 1 | SW-PB
SW4 | SW_OK | 1 | SW-PB
SW5 | SW_LT | 1 | SW-PB
SW6 | SW_RT | 1 | SW-PB
U1 | MCP1700T-3V3 SOT23-3 | 1 | SOT23-3
U1_Alt1 | MCP1700T-3V3 SOT89 | 1 | SOT89
U2 | TXB0104D | 1 | TXB0104D
U4 | DS3231N | 1 | DS3231
U7 | ATMEGA328 | 1 | TQFP32
X1 | 16MHz | 1 | Xtal_SMD2
DNP
B15 B3 B2 | I/O | 3 | I/O
J1 | ISP | 1 | ISP
J2 | FTDI | 1 | PIN_ARRAY-6X1
J3 | rtcBOB/CD | 1 | rtcBOB
J4 | SW_EXT | 1 | PIN_ARRAY_3x1
J5 | JACK_3.5MM_5PIN | 1 | Jack_3.5mm_SJ1-3513
J6 | STACK_L | 1 | STACK-L
J8 | 5V_EXT | 1 | bornier2
J10 | PWR_1 | 1 | pin_strip_2
J11 | SER_1 | 1 | pin_strip_2
J12 | PAR_1 | 1 | PIN_ARRAY_4x1
J13 | PAR_2 | 1 | SIL-8
J14 | PAR_3 | 1 | PIN_ARRAY_4x1
J15 | SER_2 | 1 | pin_strip_2
J16 | PWR_2 | 1 | pin_strip_2
J17 | STACK_R | 1 | STACK-R
J18 | EqIn_EXT | 1 | PIN_ARRAY_3x1
P1 | V_IN | 1 | JACK_ALIM
SC9 SC6 SC7 SC5 SC8 SC2 SC3 SC1 SC4 SC12 SC11 SC10 | SCREW | 12 | vite_3mm
U3 | TSOP382 | 1 | TSOP382
U6 | MSGEQ7 | 1 | SO8E
U6_Alt1 | MSGEQ7_DIP | 1 | DIP-8__300
R8 | 200k | 1 | r_0805
R6 R10 | 25k | 2 | Pot-Var2
C14 C18 | 10nF | 2 | c_0805
C15 | 33pF | 1 | c_0603
C1 C7 C9 C21 C22 C23 | 100nF | 2 | c_0805
P2 | SPK<>EQ2 | 1 | PIN_ARRAY_3x1
P3 | EQ_SH | 1 | PIN_ARRAY-6X1
POWER SUPPLY
C4 | 10uF X7R | 1 | c_1206
C6 C13 | 100nF | 2 | c_0805
C8 | 3.3nF | 1 | c_0805
C12 | 22uF X7R | 1 | c_1210
C20 C19 | 100uF | 2 | C_ELCO_SMD
D2 | BRIDGE | 1 | Bridge
J7 | V_IN | 1 | bornier2
J9 | 5V_EXT | 1 | bornier2
L1 | 2u2H, 3.0A | 1 | Inductor_SMD3
R4 | 100k | 1 | r_0805
U5 | TPS62133 | 1 | TPS62132

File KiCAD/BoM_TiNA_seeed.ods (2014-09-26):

Electronic Engineering BOM List
Product Name : TINA, WyoLum
Version：V1.0
Issue Date：19/Dec/2013
Item No. (序号) | Reference Des (上件位置) | Qty (用量) | Catalog (分类） | Part_Description (规格描述) | Part_Value （元件值） | Part_Package （元件封装） | Manufacturers Name (使用厂牌名称) | Manufacturers Part No. (使用厂牌型号) | Distributors Name （供应商名称） | Distributors Part No. (供貨商型号) | Unit Price （单价） | Price Break To Use （价格分段的购买量） | Notes/Remark （备注）
Example（填写范例）
1 | BT1 | 1 | OTHER | HOLDER BATTERY COIN 20MM DIA THM | BATT_RTC | Coin, 20.0mm | Keystone Electronics | 3003 | Digikey (http://www.digikey.com/scripts/DkSearch/dksus.dll?x=0&y=0&lang=en&KeyWords=3003K-ND&cur=USD) | 3003K-ND
2 | -- | 1 | OTHER | BATTERY LITHIUM COIN 3V 20MM | Coin Battery | CR2032 | Panasonic - BSG | CR2032 | Digikey (http://www.digikey.com/product-detail/en/CR2032/P189-ND/31939?cur=USD) | P189-ND
3 | C1 C7 C9 C21 C22 C23 | 6 | Capacitor | CAP CER 0.1UF 25V 10% X7R 0805 | 0.1µF | 0805 (2012 Metric) | Kemet | C0805C104K3RACTU | DigiKey (http://www.digikey.com/product-detail/en/C0805C104K3RACTU/399-1168-1-ND/411443) | 399-1168-1-ND
4 | C2 C5 | 2 | Capacitor | CAP CER 1UF 16V 10% X7R 0805 | 1.0µF | 0805 (2012 Metric) | Samsung Electro-Mechanics America, Inc | CL21B105KOFNNNE | DigiKey (http://www.digikey.com/product-detail/en/CL21B105KOFNNNE/1276-1026-1-ND/3889112) | 1276-1026-1-ND
5 | C3 | 1 | Capacitor | CAP CER 0.22UF 50V 10% X7R 0805 | 220nF | 0805 (2012 Metric) | Samsung Electro-Mechanics America, Inc | CL21B224KBFSFNE | DigiKey (http://www.digikey.com/product-detail/en/CL21B224KBFSFNE/1276-2948-1-ND/3891034) | 1276-2948-1-ND
6 | C10 C11 | 2 | Capacitor | CAP CER 22PF 630V 10% X7R 0805 | 22pF | 0805 (2012 Metric) | Kemet | C0805C220KBRACTU | DigiKey (http://www.digikey.com/product-detail/en/C0805C220KBRACTU/399-5568-2-ND/2033869) | 399-5568-2-ND
7 | C14 C18 | 2 | Capacitor | CAP CER 10000PF 50V 5% X7R 0805 | 10nF | 0805 (2012 Metric) | Samsung Electro-Mechanics America, Inc | CL21B103JBANNNC | DigiKey (http://www.digikey.com/product-detail/en/CL21B103JBANNNC/1276-1245-1-ND/3889331) | 1276-1245-1-ND
8 | C15 | 1 | Capacitor | CAP CER 33PF 16V 5% X7R 0603 | 33pF | 0603 (1608 Metric) | AVX Corporation | 0603YC330JAT2A | DigiKey (http://www.digikey.com/product-detail/en/0603YC330JAT2A/478-6211-1-ND/2391410) | 478-6211-1-ND
9 | C16 C17 | 2 | Capacitor | CAP CER 0.1UF 25V 10% X7R 0805 | 0.1µF | 0805 (2012 Metric) | Kemet | C0805C104K3RACTU | DigiKey (http://www.digikey.com/product-detail/en/C0805C104K3RACTU/399-1168-1-ND/411443) | 399-1168-1-ND
10 | C24 C25 C26 | 3 | Capacitor | CAP CER 22UF 16V 20% X7R 1210 | 22uF | 1210 (3225 Metric) | TDK Corporation | C3225X7R1C226M250AC | DigiKey (http://www.digikey.com/product-detail/en/C3225X7R1C226M250AC/445-3955-1-ND/1944442) | 445-3955-1-ND
11 | D1 | 1 | Diode | LED, indicator, BLINK | LED | 2-SMD, J-Lead | OSRAM Opto Semiconductors Inc | LG M67K-H1J2-24-Z | DigiKey (http://www.digikey.com/product-detail/en/LG%20M67K-H1J2-24-Z/475-2730-1-ND/1938897?cur=USD) | 475-2730-1-ND
12 | J5 | 1 | Connector | CONN JACK STEREO 5POS 3.5MM SMD | JACK_3.5MM_5PIN | 3.50mm (0.141", 1/8", Mini Plug) - Headphone | CUI Inc | SJ1-3515-SMT-TR-PI | DigiKey (http://www.digikey.com/product-detail/en/SJ1-3515-SMT-TR-PI/CP1-3515SJPICT-ND/2296003) | CP1-3515SJPICT-ND
13 | Q1 | 1 | Transistor | TRANSISTOR GP NPN AMP SOT-23 | MMBT2222 | SOT-23-3 | Fairchild Semiconductor | MMBT2222A | DigiKey (http://www.digikey.com/product-detail/en/MMBT2222A/MMBT2222AFSCT-ND/458969) | MMBT2222AFSCT-ND
14 | R1 R2 R7 R9 R11 R12 R13 R14 R15 | 9 | Resister | RES 10K OHM 1/8W 5% 0805 | 10k | 0805 (2012 Metric) | Stackpole Electronics Inc | RMCF0805JT10K0 | DigiKey (http://www.digikey.com/product-detail/en/RMCF0805JT10K0/RMCF0805JT10K0CT-ND/1942577) | RMCF0805JT10K0CT-ND
15 | R3 | 1 | Resister | RES 100 OHM 1/8W 5% 0805 | 100E | 0805 (2012 Metric) | Stackpole Electronics Inc | RMCF0805JT100R | DigiKey (http://www.digikey.com/product-detail/en/RMCF0805JT100R/RMCF0805JT100RCT-ND/1942539) | RMCF0805JT100RCT-ND
16 | R5 R16 | 2 | Resister | RES 1.5K OHM 1/8W 5% 0805 | 1k5 | 0805 (2012 Metric) | Stackpole Electronics Inc | RMCF0805JT1K50 | DigiKey (http://www.digikey.com/product-detail/en/RMCF0805JT1K50/RMCF0805JT1K50CT-ND/1942560) | RMCF0805JT1K50CT-ND
17 | R6 R10 | 2 | Resister | TRIMMER 25K OHM 0.15W TH | 25k | Square - 0.370" L x 0.368" W x 0.213" H (9.40mm x 9.35mm x 5.40mm) | CTS Electrocomponents | 262UR253B | DigiKey (http://www.digikey.com/product-detail/en/262UR253B/262UR253B-ND/3063) | 262UR253B-ND
18 | R8 | 1 | Resister | RES 200K OHM 1/8W 5% 0805 | 200k | 0805 (2012 Metric) | Stackpole Electronics Inc | RMCF0805JT200K | DigiKey (http://www.digikey.com/product-detail/en/RMCF0805JT200K/RMCF0805JT200KCT-ND/1942595) | RMCF0805JT200KCT-ND
19 | SD1 | 1 | OTHER | Micro SD Card Socket | SD_CARD_MICRO |  | ? | ? | seeed | ST-SD-006A
20 | SP1 | 1 | OTHER | BUZZER PIEZO 4KHZ 12.2MM PC MNT | Speaker | Circular - 12.20mm Dia x 6.50mm H | TDK Corporation | PS1240P02BT | DigiKey (http://www.digikey.com/product-detail/en/PS1240P02BT/445-2525-1-ND/935930) | 445-2525-1-ND
21 | SW1 SW2 SW3 SW4 SW5 SW6 | 6 | OTHER | SWITCH TACTILE SPST-NO 0.05A 12V | SW_RST SW_UP SW_DN SW_OK SW_LT SW_RT | 6.00mm x 6.00mm | TE Connectivity | 1825910-7 | DigiKey (http://www.digikey.com/product-detail/en/1825910-7/450-1804-ND/1731414) | 450-1804-ND
22 | U1 | 1 | IC | IC REG LDO 3.3V 0.25A | LDO 3V3 | SOT23-3 | Microchip Technology | MCP1700T-3302E/TT | DigiKey (http://www.digikey.com/product-search/en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) | MCP1700T3302ETTCT-ND
23 | (or U1_Alt1) |  |  |  |  | (or SOT-89-3) |  | (or MCP1700T-3302E/MB) |  | (or MCP1700T3302EMBCT-ND)
24 | U2 | 1 | IC | IC VOLT-LEVEL TRANSLATOR 14-SOIC | TXB0104D | 14-SOIC (0.154", 3.90mm Width) | Texas Instruments | TXB0104DR | DigiKey (http://www.digikey.com/product-detail/en/TXB0104DR/296-21928-1-ND/1629281) | 296-21928-1-ND
25 | U4 | 1 | IC | IC RTC W/TCXO 16-SOIC | DS3231N | 16-SOIC (0.295", 7.50mm Width) | Maxim Integrated Products | DS3231S# | DigiKey (http://goo.gl/gg9GS) | DS3231S#-ND
26 | U6 | 1 | IC | IC seven band graphic equalizer | MSGEQ7 | SO8 | MSI | MSGEQ7 | Sparkfun (https://www.sparkfun.com/products/10468) | MSGEQ7
27 | (or U6_Alt1) |  |  |  |  | DIP-8
28 | U7 | 1 | IC | IC MCU 8BIT 32KB FLASH 32TQFP | ATMEGA328P | 32-TQFP | Atmel | ATMEGA328P-AU | DigiKey (http://www.digikey.com/product-detail/en/ATMEGA328P-AU/ATMEGA328P-AU-ND/1832260) | ATMEGA328P-AU-ND
29 | X1 | 1 | OTHER | CRYSTAL 16MHZ 9PF SMD | 16MHz | 4-SMD, No Lead (DFN, LCC) | EPSON | TSX-3225 16.0000MF09Z-AC3 | DigiKey (http://www.digikey.com/product-detail/en/TSX-3225%2016.0000MF09Z-AC3/SER3628CT-ND/1802879) | SER3628CT-ND
 | POWER SUPPLY
30 | C4 | 1 |  | CAP CER 10UF 16V 10% X7R 1206 | 10uF | 1206 (3216 Metric) | Samsung Electro-Mechanics America, Inc | CL31B106KOHNNNE | DigiKey (http://www.digikey.com/product-detail/en/CL31B106KOHNNNE/1276-1082-1-ND/3889168) | 1276-1082-1-ND
31 | C6 C13 | 2 |  | CAP CER 0.1UF 25V 10% X7R 0805 | 0.1µF | 0805 (2012 Metric) | Kemet | C0805C104K3RACTU | DigiKey (http://www.digikey.com/product-detail/en/C0805C104K3RACTU/399-1168-1-ND/411443) | 399-1168-1-ND
32 | C8 | 1 |  | CAP CER 3300PF 50V 10% X7R 0805 | 3.3nF X7R | 0805 (2012 Metric) | Kemet | C0805C332K5RACTU | DigiKey (http://www.digikey.com/product-detail/en/C0805C332K5RACTU/399-1153-1-ND/411428) | 399-1153-1-ND
33 | C12 | 1 |  | CAP CER 22UF 16V 20% X7R 1210 | 22uF | 1210 (3225 Metric) | TDK Corporation | C3225X7R1C226M250AC | DigiKey (http://www.digikey.com/product-detail/en/C3225X7R1C226M250AC/445-3955-1-ND/1944442) | 445-3955-1-ND
34 | C19 C20 | 2 |  | CAP ALUM 100UF 35V 20% SMD | 100uF | Radial, Can - SMD | Nichicon | UWT1V101MCL1GS | DigiKey (http://www.digikey.com/product-detail/en/UWT1V101MCL1GS/493-2203-1-ND/590178) | 493-2203-1-ND
35 | D2 | 1 |  | RECT BRIDGE GPP 4A 1000V GBU | Bridge | Through Hole | Micro Commercial Co | GBU4M-BP | DigiKey (http://www.digikey.com/product-detail/en/GBU4M-BP/GBU4M-BPMS-ND/1140594) | GBU4M-BPMS-ND
36 | J7 J9 | 2 |  | TERM BLOCK 5.08MM VERT 2POS PCB | V_IN 5V_EXT | Through Hole, 0.2” | On Shore Technology Inc | OSTTA024163 | DigiKey (http://www.digikey.com/product-detail/en/OSTTA024163/ED2580-ND/614529) | ED2580-ND
37 | L1 | 1 |  | Power Inductor 2.2 uH 20 % 8 A | 2.2uH | 4.3 mm W x 4.3 mm L x 2.1 mm H | Coilcraft | XFL4020-222MEB | Mouser (http://in.mouser.com/ProductDetail/Coilcraft/XFL4020-222MEB/?qs=VJjuEbE9QBO2bwonVBK1EA==) | 994-XFL4020-222MEB
38 | R4 | 1 |  | RES 100K OHM 1/8W 5% 0805 | 100k | 0805 (2012 Metric) | Stackpole Electronics Inc | RMCF0805JT100K | DigiKey (http://www.digikey.com/product-detail/en/RMCF0805JT100K/RMCF0805JT100KCT-ND/1942592) | RMCF0805JT100KCT-ND
39 | U5 | 1 |  | IC REG BUCK SYNC 5V 3A 16QFN | TPS62133 | 16-VFQFN Exposed Pad | Texas Instruments | TPS62133RGTT | DigiKey (http://www.digikey.com/product-detail/en/TPS62133RGTT/296-30225-1-ND/2982139) | 296-30225-1-ND
 | DO NOT POPULATE |  |  | (PLEASE ADD AS KIT PARTS)
40 | J1 | 1 |  | CONN HEADER .100" DUAL STR 6POS | ISP | Dual row, 0.1” | Sullins Connector Solutions | PREC003DAAN-RC | DigiKey (http://www.digikey.com/product-detail/en/PREC003DAAN-RC/S2012EC-03-ND/2774891) | S2012EC-03-ND
41 | J2 J4 J6 J10 J11 J12 J13 J14 J15 J16 J17 J18 | 1 |  | CONN HEADER .100" SNGL STR 40POS | PWR_1 SER_1 PAR_1 PAR_2 PAR_3 SER_2 PWR_2 STACK_R EqIn_EXT FTDI SW_EXT STACK_L | Single row, 0.1” | Sullins Connector Solutions | PREC040SAAN-RC | DigiKey (http://www.digikey.com/product-detail/en/PREC040SAAN-RC/S1012EC-40-ND/2774814) | S1012EC-40-ND
42 | J8 | 1 |  | TERM BLOCK 5.08MM VERT 2POS PCB | 5V_EXT | Through Hole, 0.2” | On Shore Technology Inc | OSTTA024163 | DigiKey (http://www.digikey.com/product-detail/en/OSTTA024163/ED2580-ND/614529) | ED2580-ND
43 | U3 | 1 |  | IC IR RCVR MOD 38KHZ DOME AXIAL | TSOP382 | Side View | Vishay Semiconductor Opto Division | TSOP38238 | DigiKey (http://www.digikey.com/product-detail/en/TSOP38238/751-1227-ND/1681362) | 751-1227-ND
44 | P2 P3 | 1 |  | CONN HEADER .100" SNGL STR 10POS | SPK<>EQ2 EQ_SH | Single row, 0.1” | Sullins Connector Solutions | PREC040SAAN-RC | DigiKey (http://www.digikey.com/product-detail/en/PREC040SAAN-RC/S1012EC-40-ND/2774814) | S1012EC-40-ND
1. Recommended Distributor: Digi-Key, Mouser, Avnet Express, Farnell.
2. Catalog: Capacitor,Resister,Diode,Connector,Transistor,IC,PROTECTOR CATEGORY,OTHER
3. Required Fields: Item No, Reference Des, Qty, Catalog, Part_Value, Part Package
Optional Fields: Part_Description, Manufacturers Name, Manufacturers Part No, Distributors Name, Distributors Part No, Unit Cost, Price break to use, Notes/Remark

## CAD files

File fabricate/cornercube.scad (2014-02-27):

$fn=100;

mm = 1;
inch = 25.4 * mm;

LENGTH = .75 * inch;
EDGE_WIDTH = .5 * inch;
THICKNESS = .2 * inch;

MATERIAL_THICKNESS = 3 * mm;
OFFSET = .4 * inch;

HEX_R = 6.1 * mm / 2;
HEX_r = 5.6 * mm / 2;
HEX_THICKNESS = 2 * mm; 

//HEX_THICKNESS = 1.5 * mm; // for thin version
//THICKNESS = 3 * mm; // for thin version

SCREW_R = 1.6 * mm;
module hex(){
  difference(){
    cylinder(r=HEX_R, h=HEX_THICKNESS);
    for(i=[0, 1, 2, 3, 4, 5]){
      rotate(a=60 * i, v=[0, 0, 1])
      translate([HEX_r, -5, 5])rotate(a=90, v=[0, 1, 0])cube([10, 10, HEX_THICKNESS]);
    }
  }
}

TAB_HEIGHT = .5*mm;
TAB_R = 5*mm;
// tab to prevent rollup
module tab(x, y){
  translate([x, y])cylinder(r=TAB_R, h=TAB_HEIGHT);
}

module edge(){
  difference(){
    union(){
      difference(){
	cube([OFFSET, EDGE_WIDTH, OFFSET]);
	translate([THICKNESS, -.01 * EDGE_WIDTH/2, THICKNESS])scale([1, 1.01, 1])cube([LENGTH, EDGE_WIDTH, LENGTH]);
      }
      union(){
	translate([OFFSET, EDGE_WIDTH/2, 0])cylinder(r=EDGE_WIDTH / 2, h=THICKNESS);
	translate([0, EDGE_WIDTH/2, OFFSET])rotate(v=[0, 1, 0], a=90)cylinder(r=EDGE_WIDTH / 2, h=THICKNESS);
      }
    }
    translate([OFFSET, EDGE_WIDTH/2, 0])cylinder(r=SCREW_R, h=THICKNESS * 1.1);
    translate([-.01, EDGE_WIDTH/2, OFFSET])rotate(v=[0, 1, 0], a=90)cylinder(r=SCREW_R, h=THICKNESS * 10);
  }
}

module inside_edge(){
  difference(){
    edge();
    translate([OFFSET, EDGE_WIDTH/2, THICKNESS - HEX_THICKNESS])scale([1, 1, 1.01])hex();
    translate([THICKNESS - HEX_THICKNESS, EDGE_WIDTH/2, OFFSET])rotate(v=[0, 1, 0], a=90)scale([1, 1, 1.01])hex();
  }
}
module outside_edge(){
  difference(){
    edge();
    translate([OFFSET, EDGE_WIDTH/2, 0])scale([1, 1, 1.01])cylinder(r=HEX_R * 1.1, h=HEX_THICKNESS);
    translate([0, EDGE_WIDTH/2, OFFSET])scale([1, 1, 1.01])rotate(v=[0, 1, 0], a=90)cylinder(r=HEX_R * 1.1, h=HEX_THICKNESS);
  }
}

module corner(length, thickness, offset){
  echo("offset", offset);
  LENGTH = length;
  THICKNESS = thickness;
  OFFSET = offset;
  union(){
    //tab(0, 0);
    //tab(LENGTH, 0);
    //tab(0, LENGTH);

    intersection(){
      difference(){
	cube(LENGTH);
	translate([THICKNESS, THICKNESS, THICKNESS])
	  cube(LENGTH);
	translate([OFFSET, OFFSET, 0])
	  translate([0, 0, -1])
	  cylinder(r=SCREW_R, h=2 * THICKNESS);
	translate([OFFSET, 0, OFFSET])
	  rotate(v=[-1, 0, 0], a=90) 
	  translate([0, 0, -1])
	  cylinder(r=SCREW_R, h=2 * THICKNESS);
	translate([0, OFFSET, OFFSET])
	  rotate(v=[0, 1, 0], a=90)
	  translate([0, 0, -1])
	  cylinder(r=SCREW_R, h=2 * THICKNESS);
      }
      
      union(){
	rotate(v=[0, 0, -1], a=0)cylinder(r=LENGTH*1.04, h=THICKNESS);
	rotate(v=[-1,0, 0], a=90)cylinder(r=LENGTH*1.04, h=THICKNESS);
	rotate(v=[0, 1, 0], a=90)cylinder(r=LENGTH*1.04 , h=THICKNESS);
      }
      // sphere(r=LENGTH);
    }
  }
}
module inside_corner(length, thickness, offset){
  LENGTH = length;
  THICKNESS = thickness;
  OFFSET = offset;

  difference(){
    corner(LENGTH, THICKNESS, OFFSET);
    translate([OFFSET, OFFSET, THICKNESS - HEX_THICKNESS])scale([1, 1, 100])hex();
    translate([OFFSET, THICKNESS - HEX_THICKNESS,  OFFSET])
      rotate(v=[-1, 0, 0], a=90)
      scale([1, 1, 100])
      hex();
    translate([THICKNESS - HEX_THICKNESS, OFFSET,  OFFSET])
      rotate(v=[0, 1, 0], a=90) // correct one!
      scale([1, 1, 100])
      hex();
  }
}
module outside_corner(length, thickness, offset, material_thickness){
  LENGTH = length + (material_thickness + thickness) * sqrt(2);
  THICKNESS = thickness;
  OFFSET = offset + material_thickness + thickness;
  echo("OFFSET", OFFSET);
  difference(){
    union(){
      corner(LENGTH, THICKNESS, OFFSET);
    }

    // counter bore
    translate([OFFSET,  HEX_THICKNESS, OFFSET])
      rotate(v=[1, 0, 0], a=90)
      rotate(v=[0, 0, 1], a=180)
      scale([1, 1, 100])
      cylinder(r=HEX_R * 1.1);
    translate([HEX_THICKNESS, OFFSET, OFFSET])
      rotate(v=[0, -1, 0], a=90)
      scale([1, 1, 100])
      cylinder(r=HEX_R * 1.1);
    translate([OFFSET,  OFFSET, HEX_THICKNESS, ])
      rotate(v=[0, 1, 0], a=180)
      scale([1, 1, 100])
      cylinder(r=HEX_R * 1.1);
  }
}

//translate([0, MATERIAL_THICKNESS + THICKNESS, MATERIAL_THICKNESS + THICKNESS])inside_corner(LENGTH, THICKNESS, OFFSET);
translate([-MATERIAL_THICKNESS - THICKNESS, 0, 0])outside_corner(LENGTH, THICKNESS, OFFSET, MATERIAL_THICKNESS);
//translate([-2 * inch, 0, 0])
// inside_corner();
// inside_edge();

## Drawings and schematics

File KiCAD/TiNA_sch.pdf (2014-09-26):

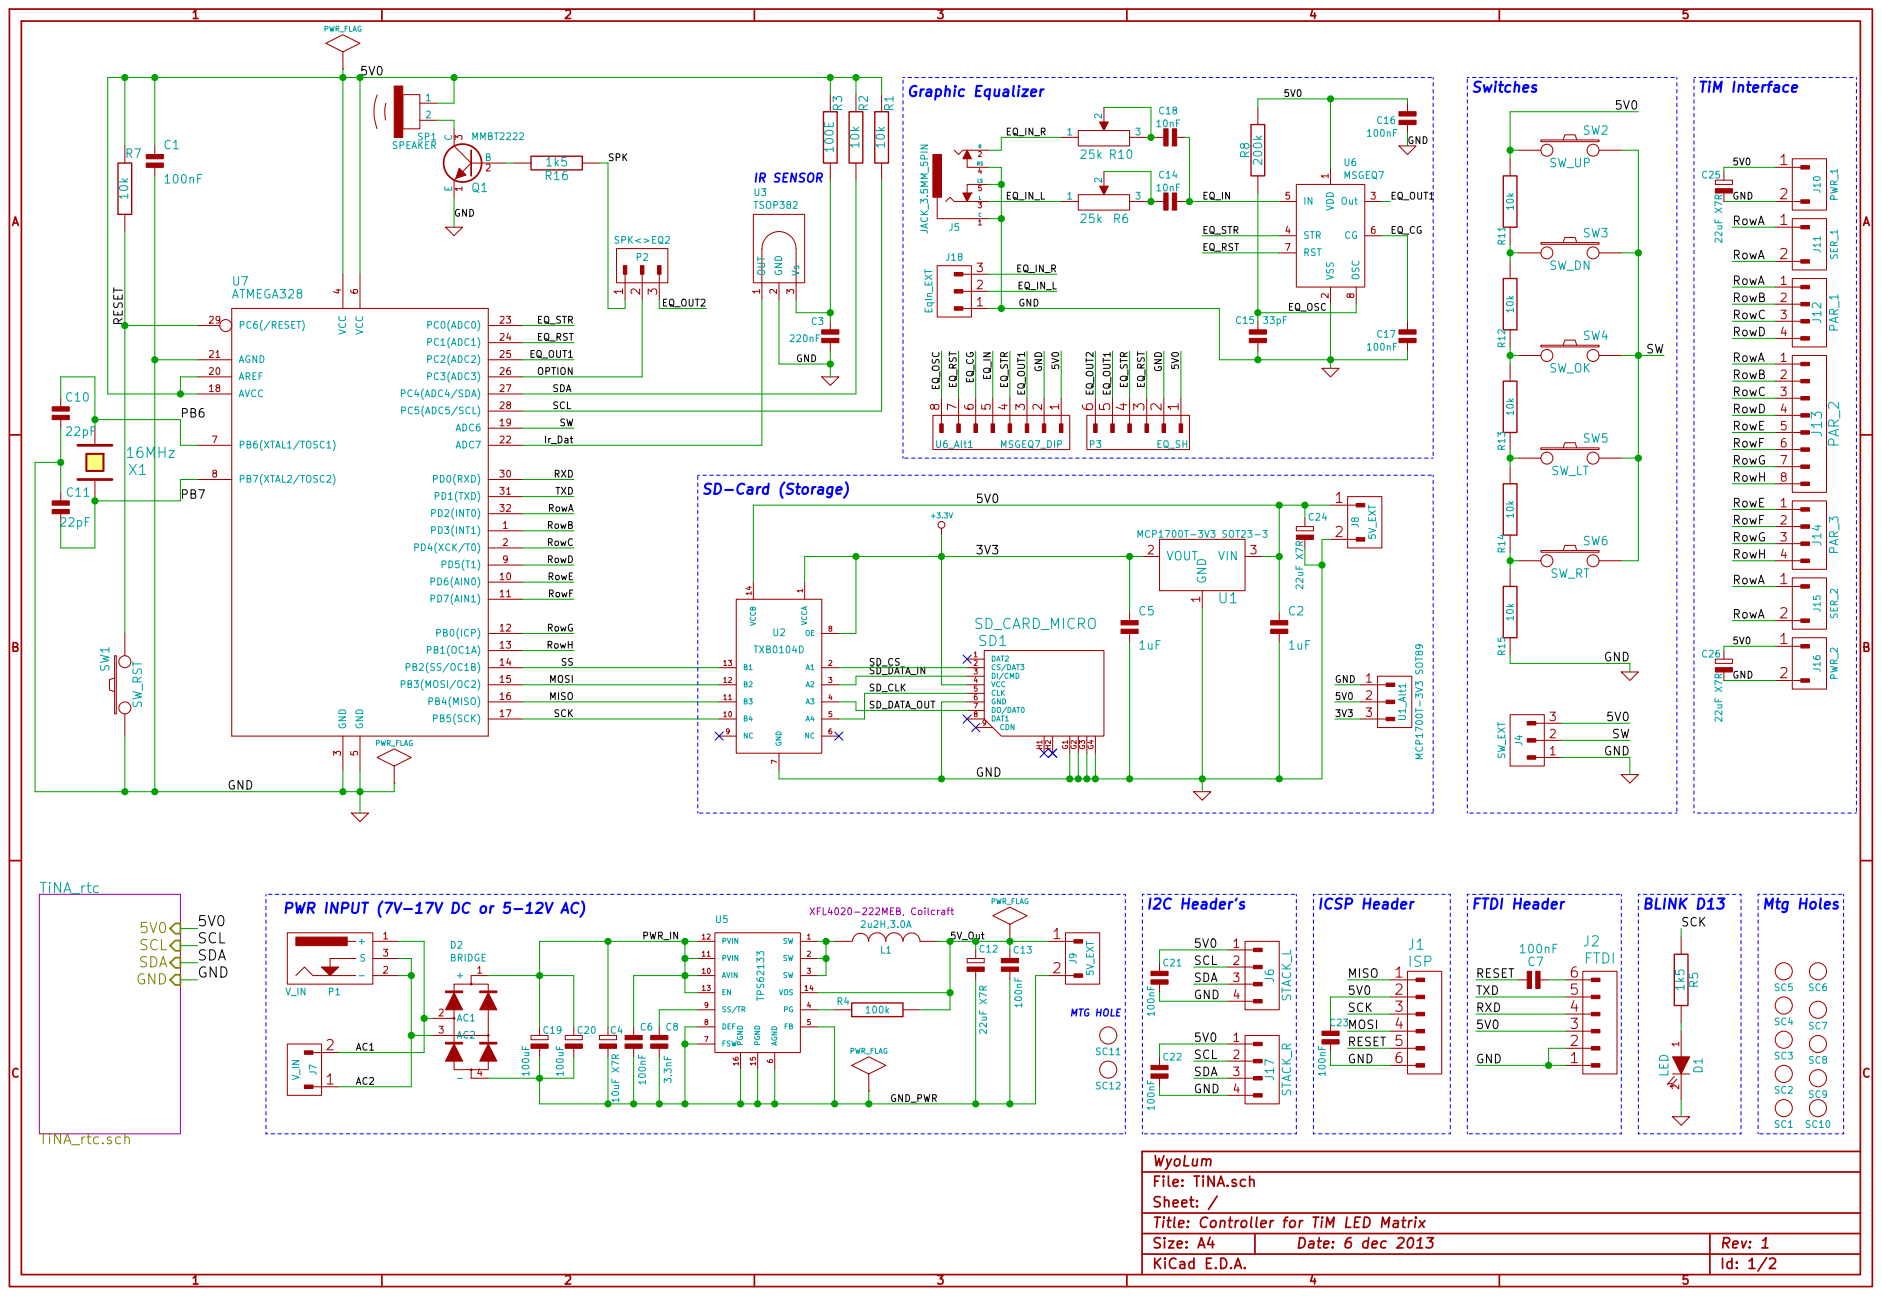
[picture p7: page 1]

5V0 GND RowA RowA RowA RowA RowA RowB RowC

6 PB6(XTAL1/TOSC1) 7 PB7(XTAL2/TOSC2) 8 PD5(T1) 9 PD6(AIN0) 10 AREF 20 PD0(RXD) 30 PD7(AIN1) 11 AGND 21 PD1(TXD) 31 PB0(ICP) 12 ADC7 22 PD2(INT0) 32 PB1(OC1A) 13 PC0(ADC0) 23 PB2(SS/OC1B) 14 PC1(ADC1) 24 PB3(MOSI/OC2) 15 PC2(ADC2) 25 PB4(MISO) 16 PC3(ADC3) 26 PB5(SCK) 17 PC4(ADC4/SDA) 27 AVCC 18 PC5(ADC5/SCL) 28 ADC6 19 PC6(/RESET) 29 U7 ATMEGA328

6 FSW 7 DEF 8 SS/TR 9 AVIN 10 PVIN 11 PVIN 12 EN 13 VOS 14 PGND 15 PGND 16 U5 TPS62133 C6100nF C83.3nF RowA RowB RowC

WyoLum
Title: Controller for TiM LED Matrix File: TiNA.sch Sheet: /

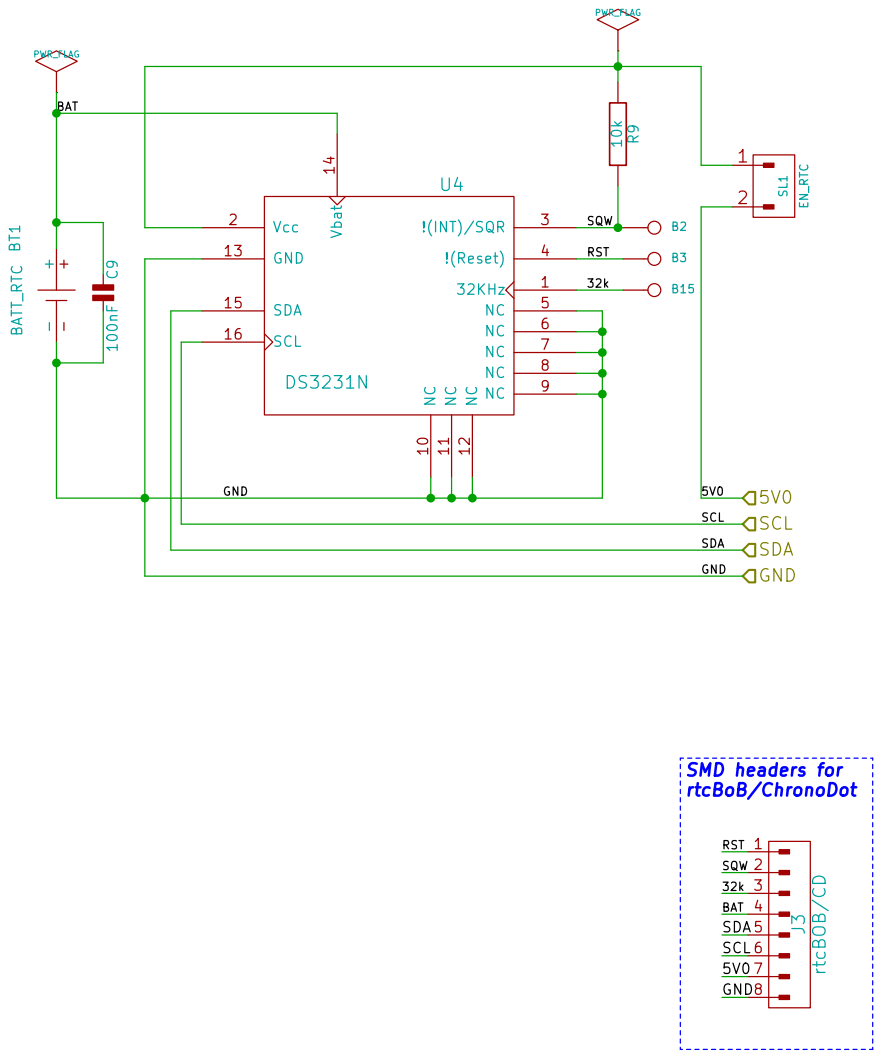
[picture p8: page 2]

RST SMD headers for
rtcBoB/ChronoDot GND

File: TiNA_rtc.sch
Sheet: /TiNA_rtc/
Title: Controller for TiM LED Matrix

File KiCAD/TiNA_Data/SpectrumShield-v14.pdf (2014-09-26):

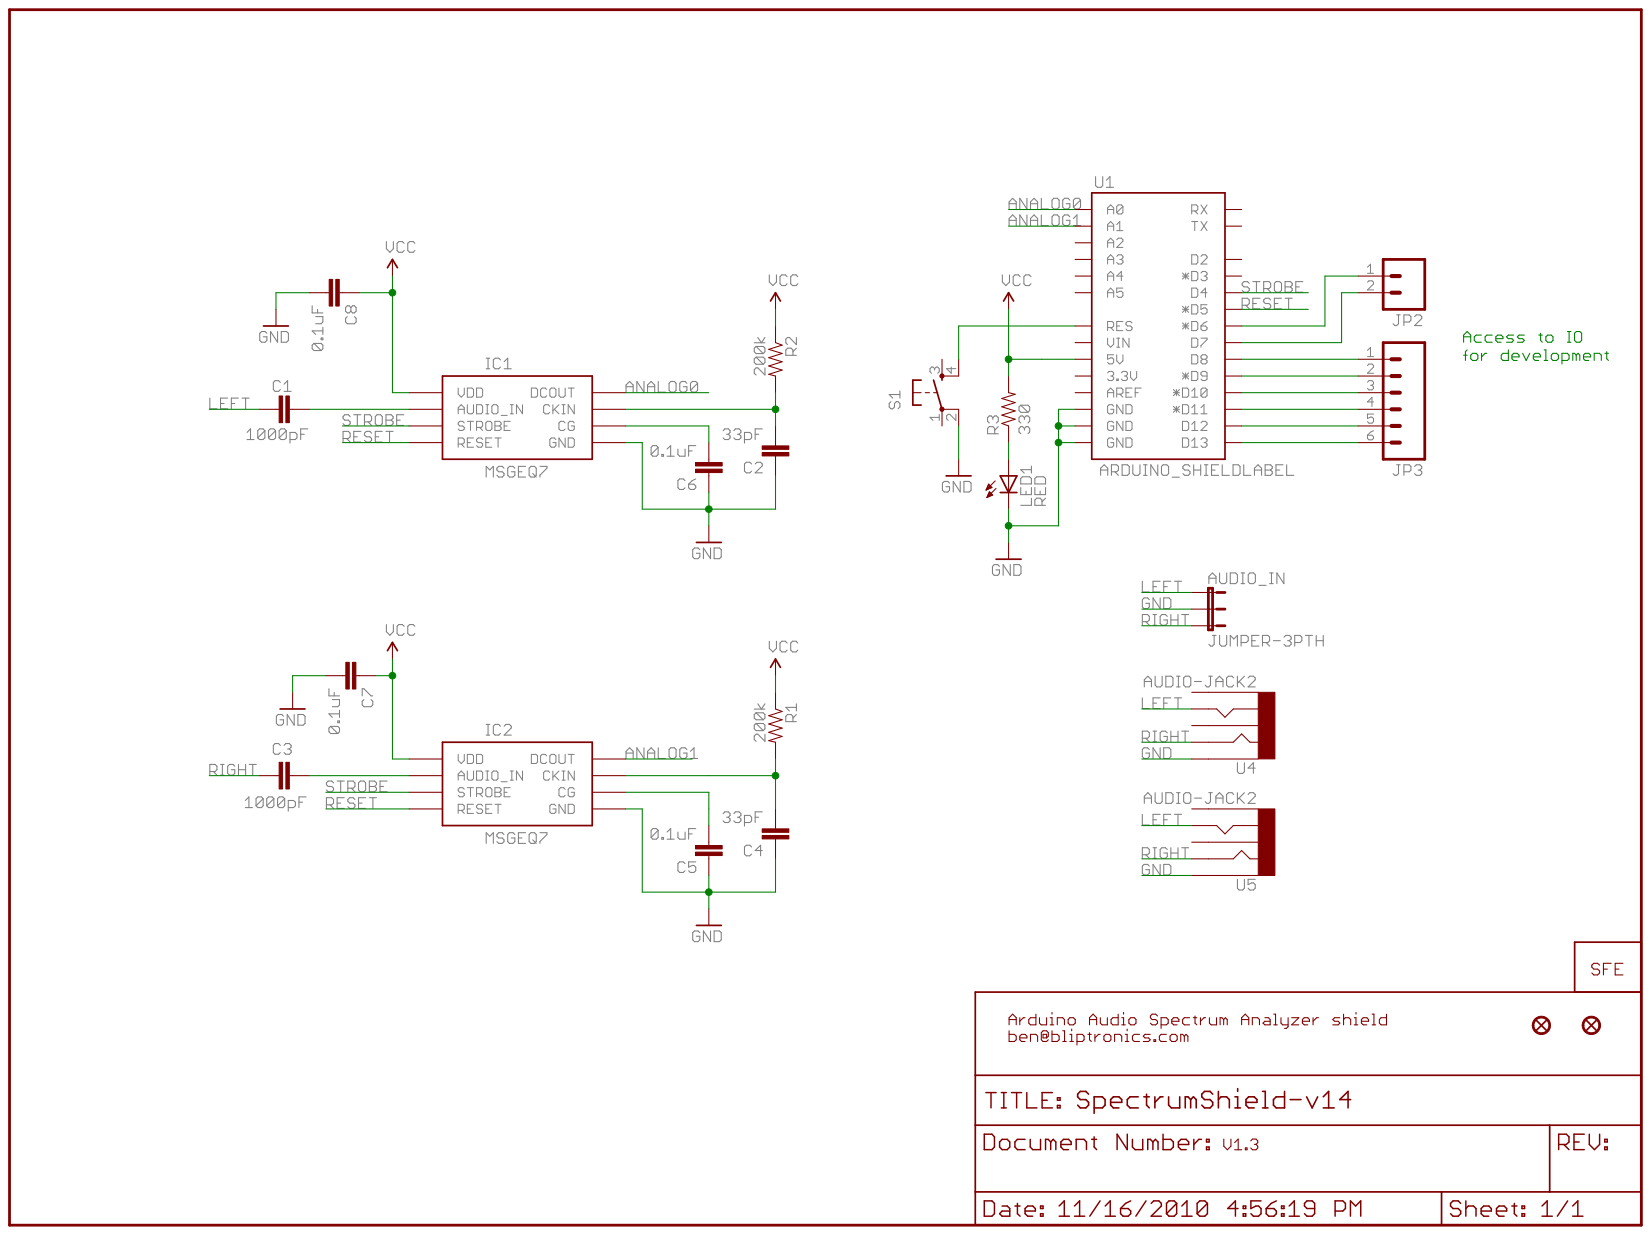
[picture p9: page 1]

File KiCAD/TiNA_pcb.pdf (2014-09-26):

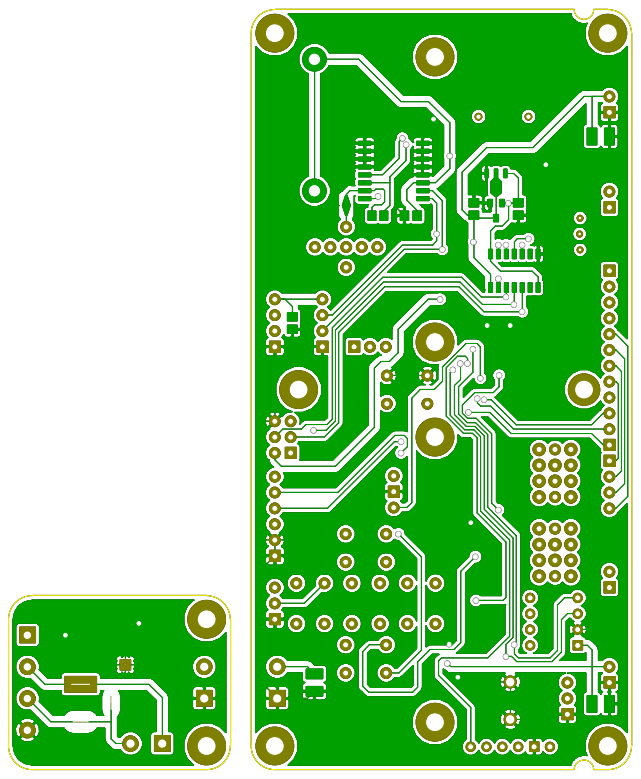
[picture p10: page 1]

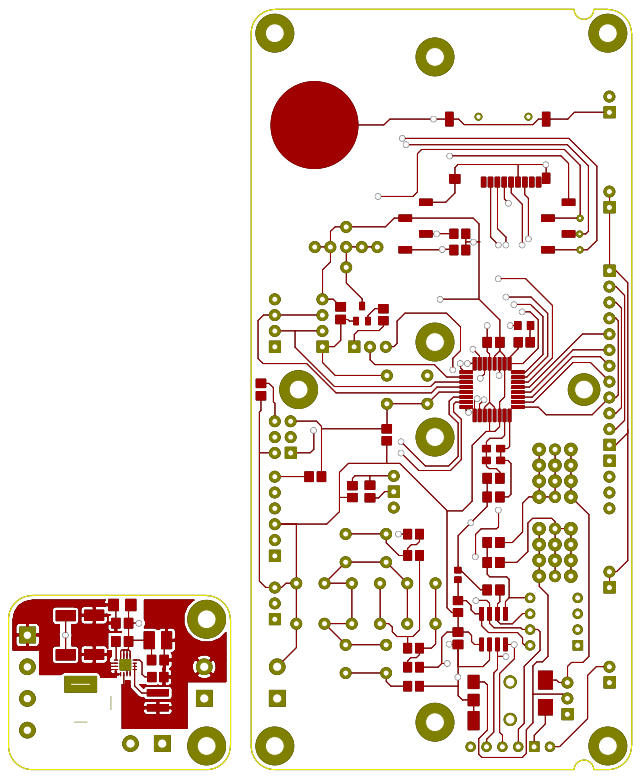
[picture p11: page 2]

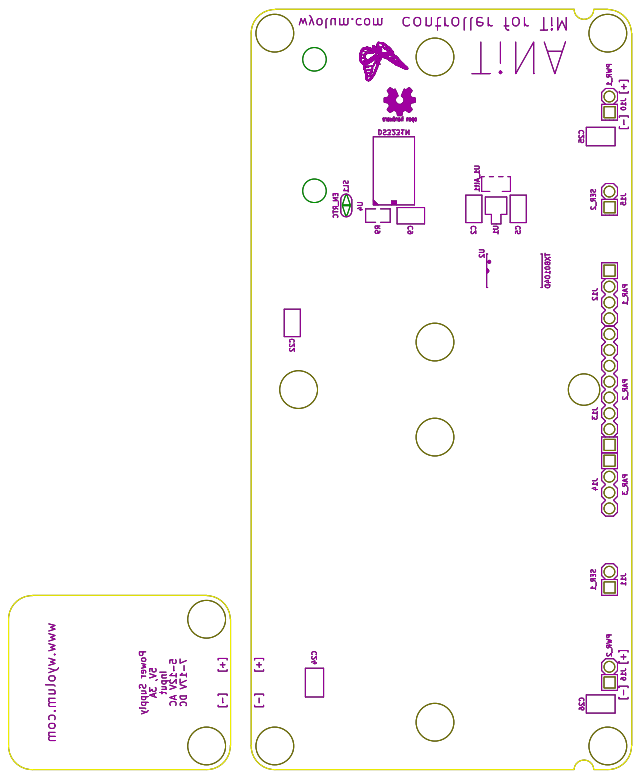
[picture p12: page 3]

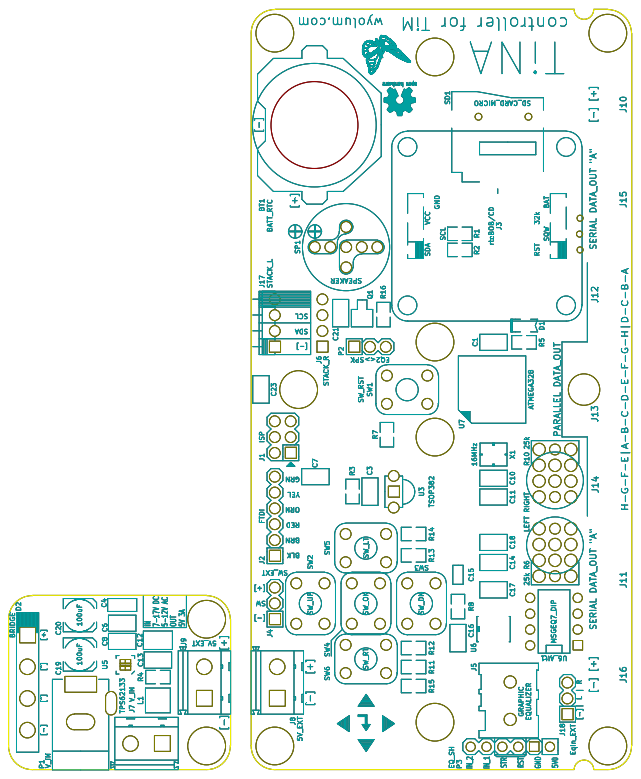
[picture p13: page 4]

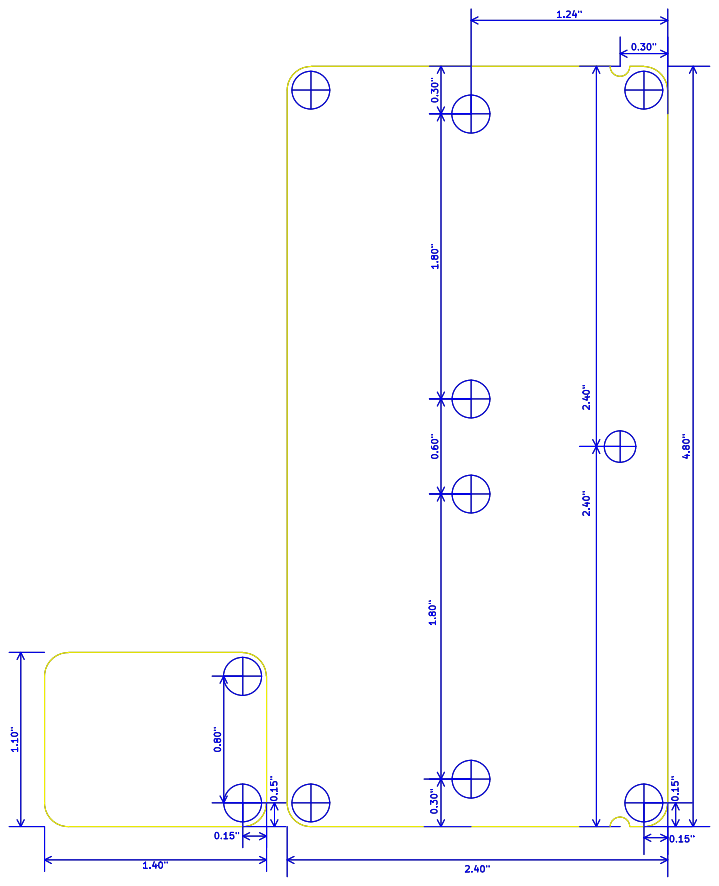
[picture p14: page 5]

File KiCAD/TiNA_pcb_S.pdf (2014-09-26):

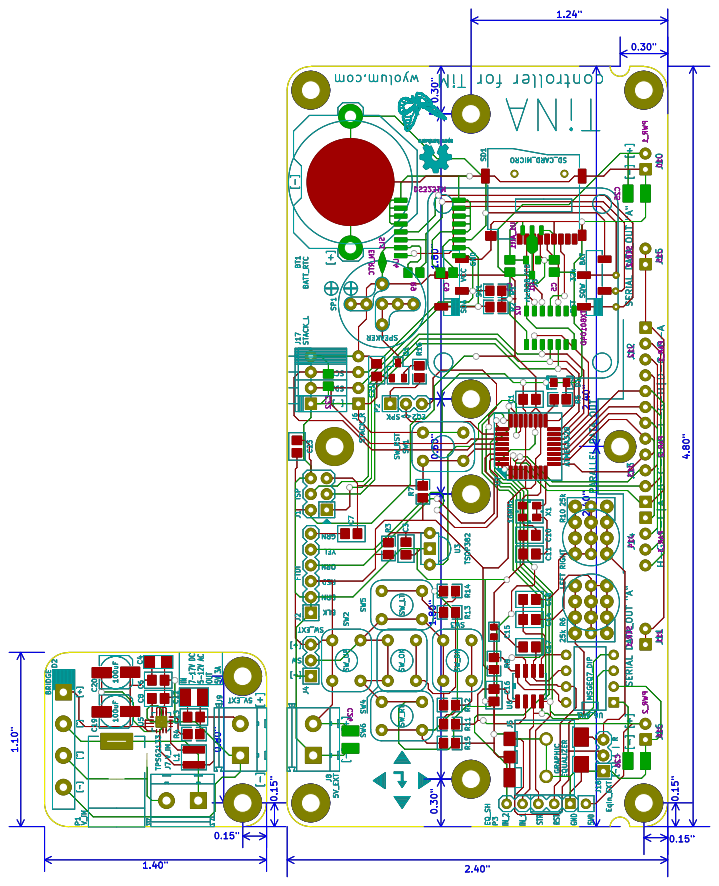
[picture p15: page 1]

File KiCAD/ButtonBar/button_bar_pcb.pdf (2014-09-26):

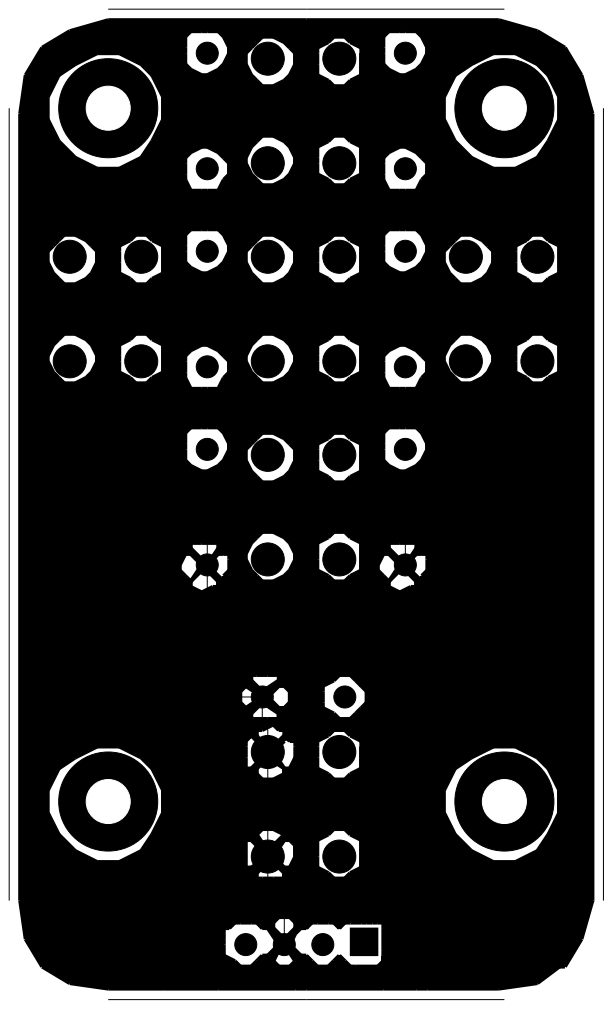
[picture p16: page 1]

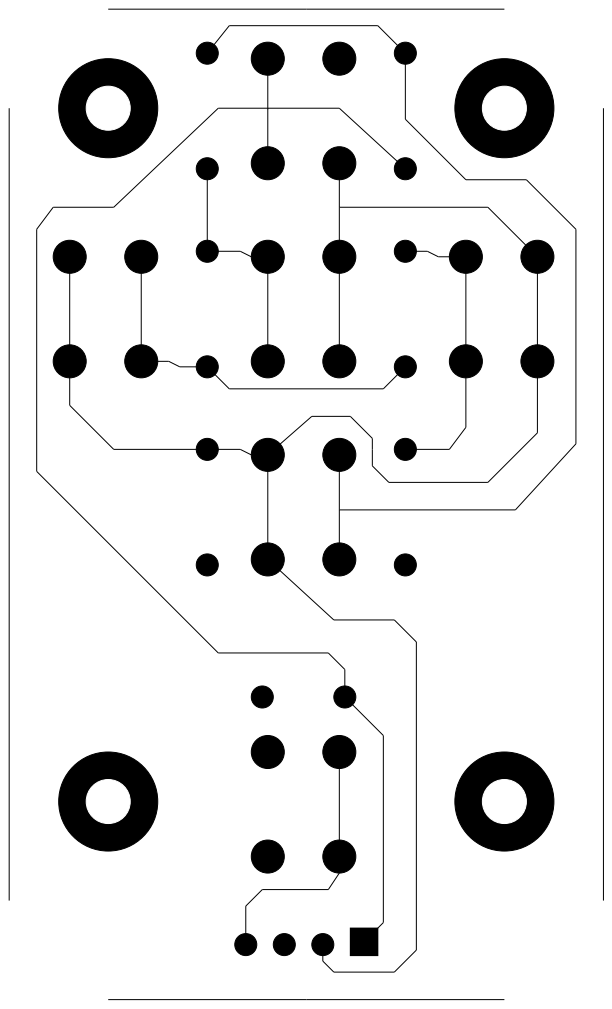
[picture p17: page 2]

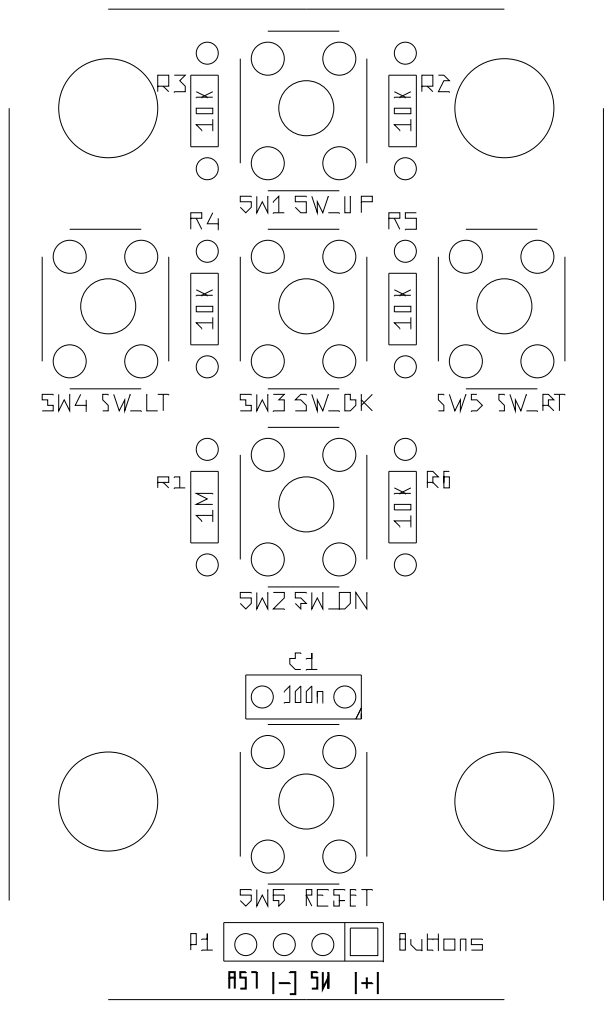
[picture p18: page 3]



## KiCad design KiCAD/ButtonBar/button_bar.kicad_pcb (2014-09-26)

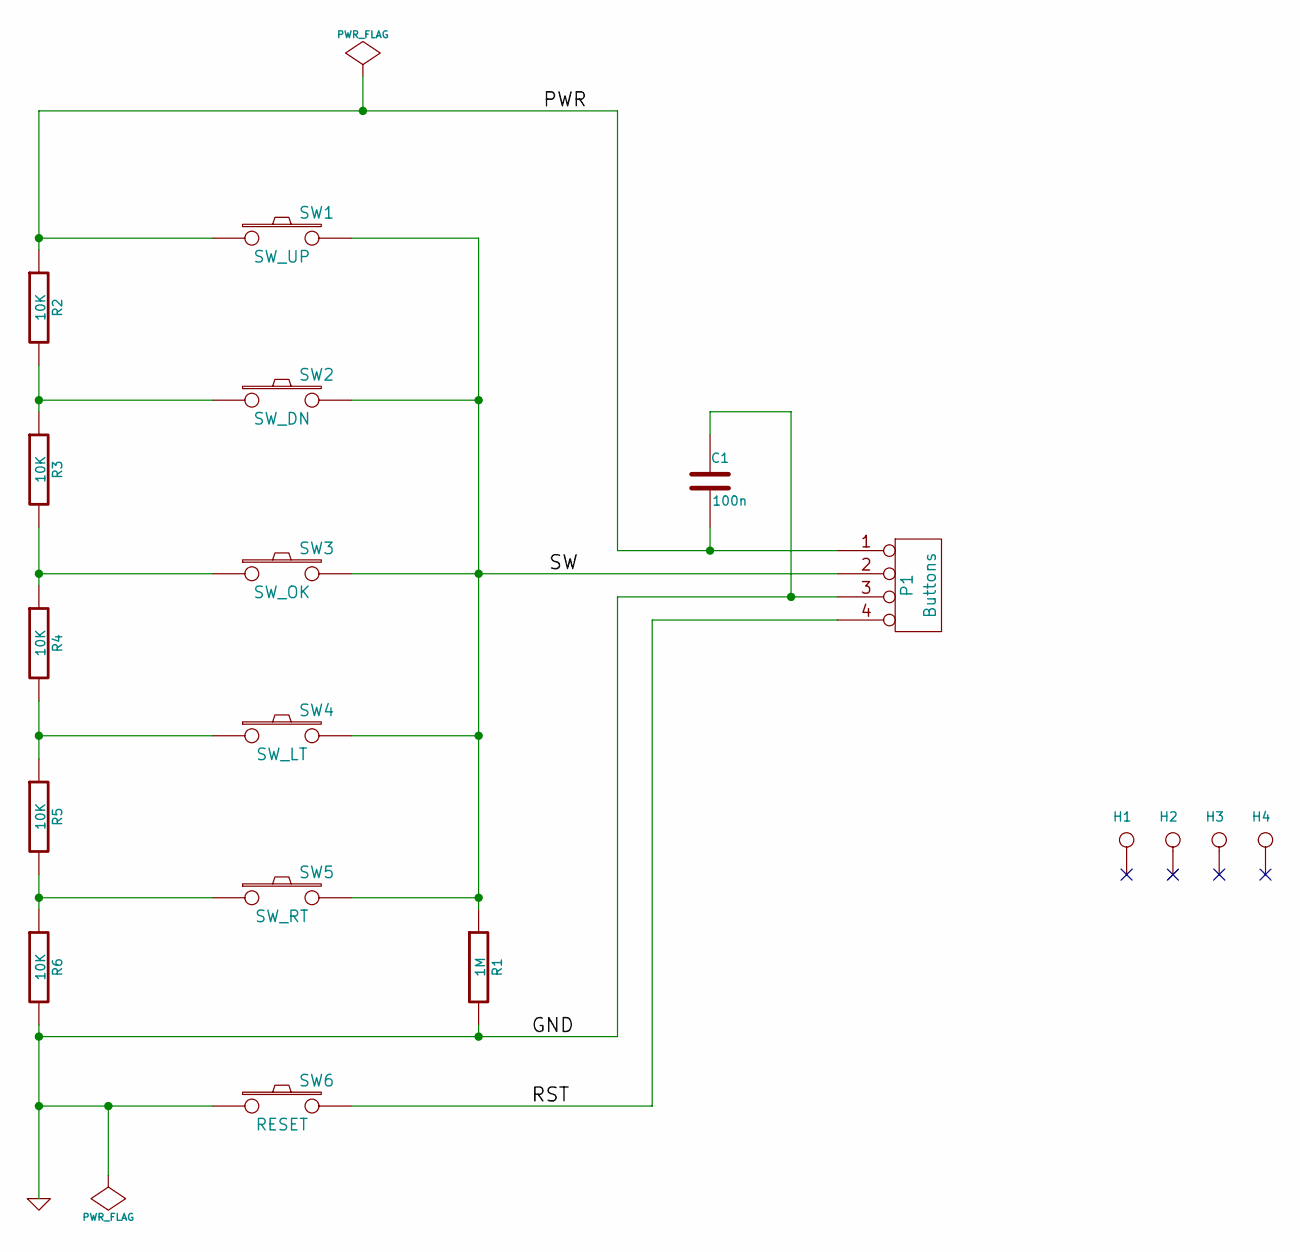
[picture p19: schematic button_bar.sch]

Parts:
C1: 100n; C2
H1, H2, H3, H4: CONN_1
P1: Buttons; SIL-4
R1: 1M; RC03
R2, R3, R4, R5, R6: 10K; RC03
SW1: SW_UP; SW-PB
SW2: SW_DN; SW-PB
SW3: SW_OK; SW-PB
SW4: SW_LT; SW-PB
SW5: SW_RT; SW-PB
SW6: RESET; SW-PB

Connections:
/PWR: C1.2, P1.1, R2.1, SW1.1
/RST: P1.4, SW6.2
/SW: P1.2, R1.1, SW1.2, SW2.2, SW3.2, SW4.2, SW5.2
GND: C1.1, P1.3, R1.2, R6.2, SW6.1
unnamed: R3.2, R4.1, SW3.1
unnamed: R5.2, R6.1, SW5.1
unnamed: R4.2, R5.1, SW4.1
unnamed: R2.2, R3.1, SW2.1

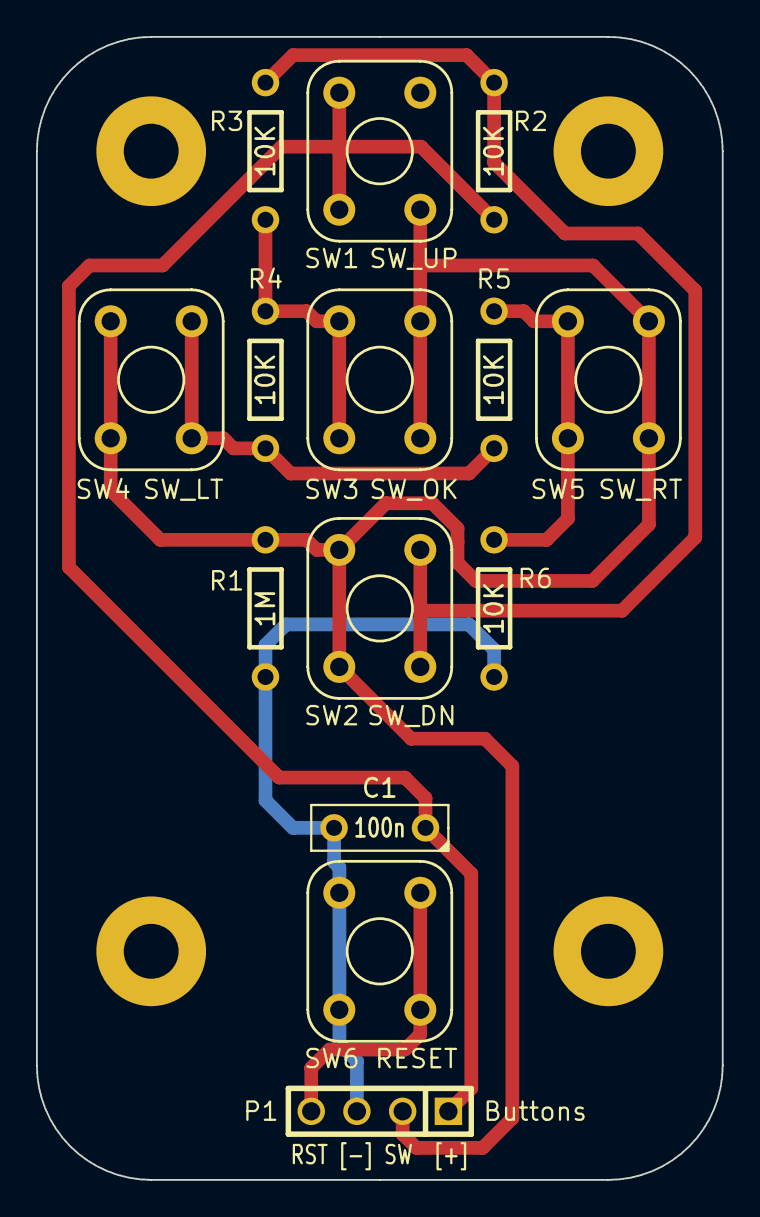
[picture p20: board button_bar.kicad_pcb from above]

Board: 2 copper layers, 38.1 x 63.5 mm, 18 parts (0 on the bottom side), 8 nets.

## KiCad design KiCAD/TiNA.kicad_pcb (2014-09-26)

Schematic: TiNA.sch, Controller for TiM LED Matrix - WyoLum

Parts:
C1, C6, C7, C13, C16, C17, C21, C22, C23: 100nF; c_0805
C2, C5: 1uF; c_0805
C3: 220nF; c_0805
C4: 10uF X7R; c_1206
C8: 3.3nF; c_0805
C10, C11: 22pF; c_0805; Digikey 490-1734-1-ND
C12, C24, C25, C26: 22uF X7R; c_1210
C14, C18: 10nF; c_0805
C15: 33pF; c_0603
C19, C20: 100uF; C_ELCO_SMD
D1: LED; d_0805
D2: BRIDGE; Bridge
J1: ISP
J2: FTDI; PIN_ARRAY-6X1
J4: SW_EXT; PIN_ARRAY_3x1
J5: JACK_3.5MM_5PIN; Jack_3.5mm_SJ1-3513
J6: STACK_L; STACK-L
J7: V_IN; bornier2
J8, J9: 5V_EXT; bornier2
J10: PWR_1; pin_strip_2
J11: SER_1; pin_strip_2
J12: PAR_1; PIN_ARRAY_4x1
J13: PAR_2; SIL-8
J14: PAR_3; PIN_ARRAY_4x1
J15: SER_2; pin_strip_2
J16: PWR_2; pin_strip_2
J17: STACK_R; STACK-R
J18: EqIn_EXT; PIN_ARRAY_3x1
L1: 2u2H,3.0A; Inductor_SMD3; Mfr_PN XFL4020-222MEB, Coilcraft
P1: V_IN; JACK_ALIM
P2: EQ2<>SPK; PIN_ARRAY_3x1
P3: EQ_SH; PIN_ARRAY-6X1
Q1: MMBT2222; SOT23-3-NPN
R1, R2, R7, R11, R12, R13, R14, R15: 10k; r_0805
R3: 100E; r_0805
R4: 100k; r_0805
R5, R16: 1k5; r_0805
R6, R10: 25k; Pot-Var2
R8: 200k; r_0805
SC1, SC2, SC3, SC4, SC5, SC6, SC7, SC8, SC9, SC10, SC11, SC12: SCREW; vite_3mm
SD1: SD_CARD_MICRO; SD_Micro_seeed
SP1: SPEAKER; Speaker_2
SW1: SW_RST; SW-PB
SW2: SW_UP; SW-PB
SW3: SW_DN; SW-PB
SW4: SW_OK; SW-PB
SW5: SW_LT; SW-PB
SW6: SW_RT; SW-PB
U1: MCP1700T-3V3 SOT23-3; SOT23-3; Part No MCP1700T-3302E/TT
U1_Alt1: MCP1700T-3V3 SOT89; SOT89
U2: TXB0104D
U3: TSOP382
U5: TPS62133; TPS62132
U6: MSGEQ7; SO8E
U6_Alt1: MSGEQ7_DIP; DIP-8__300
U7: ATMEGA328; TQFP32
X1: 16MHz

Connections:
+3.3V: C5.1, SD1.4, U1.2 (VOUT), U1_Alt1.3, U2.1 (VCCA), U2.8 (OE)
/5V_Out: C12.1, C13.2, J9.1, L1.2, R4.2, U5.14 (VOS)
/AC1: D2.2 (AC1), J7.2 (PM), P1.1 (+)
/AC2: D2.3 (AC2), J7.1, P1.2 (-), P1.3 (S)
/EQ_CG: C17.2, U6.6 (CG), U6_Alt1.6
/EQ_IN: C14.1, C18.1, U6.5 (IN), U6_Alt1.5
/EQ_IN_L: J5.3, J18.2, R6.1
/EQ_IN_R: J5.2, J18.3, R10.1
/EQ_OSC: C15.1, R8.1, U6.8 (OSC), U6_Alt1.8
/EQ_OUT1: P3.5, U6.3 (Out), U6_Alt1.3, U7.25 (PC2(ADC2))
/EQ_OUT2: P2.3, P3.6
/EQ_RST: P3.3, U6.7 (RST), U6_Alt1.7, U7.24 (PC1(ADC1))
/EQ_STR: P3.4, U6.4 (STR), U6_Alt1.4, U7.23 (PC0(ADC0))
/GND_PWR: C4.2, C6.1, C8.1, C12.2, C13.1, C19.2, C20.2, D2.4 (-), J9.2 (PM), U5.5 (FB), U5.6 (AGND), U5.7 (FSW), U5.8 (DEF), U5.15 (PGND), U5.16 (PGND)
/Ir_Dat: U3.1 (OUT), U7.22 (ADC7)
/MISO: J1.1, U2.11 (B3), U7.16 (PB4(MISO))
/MOSI: J1.4, U2.12 (B2), U7.15 (PB3(MOSI/OC2))
/OPTION: P2.2, U7.26 (PC3(ADC3))
/PB6: C10.1, U7.7 (PB6(XTAL1/TOSC1)), X1.1
/PB7: C11.1, U7.8 (PB7(XTAL2/TOSC2)), X1.2
/PWR_IN: C4.1, C6.2, C19.1, C20.1, D2.1 (+), U5.10 (AVIN), U5.11 (PVIN), U5.12 (PVIN), U5.13 (EN)
/RESET: C7.2, J1.5, R7.2, SW1.2, U7.29 (PC6(/RESET))
/RXD: J2.4, U7.30 (PD0(RXD))
/RowA: J11.1, J11.2 (PM), J12.1, J13.1, J15.1, J15.2 (PM), U7.32 (PD2(INT0))
/RowB: J12.2, J13.2, U7.1 (PD3(INT1))
/RowC: J12.3, J13.3, U7.2 (PD4(XCK/T0))
/RowD: J12.4, J13.4, U7.9 (PD5(T1))
/RowE: J13.5, J14.1, U7.10 (PD6(AIN0))
/RowF: J13.6, J14.2, U7.11 (PD7(AIN1))
/RowG: J13.7, J14.3, U7.12 (PB0(ICP))
/RowH: J13.8, J14.4, U7.13 (PB1(OC1A))
/SCK: J1.3, R5.1, U2.10 (B4), U7.17 (PB5(SCK))
/SD_CLK: SD1.5, U2.5 (A4)
/SD_CS: SD1.2, U2.2 (A1)
/SD_DATA_IN: SD1.3, U2.3 (A2)
/SD_DATA_OUT: SD1.7, U2.4 (A3)
/SPK: P2.1, R16.1
/SS: U2.13 (B1), U7.14 (PB2(SS/OC1B))
/SW: J4.2, SW2.2, SW3.2, SW4.2, SW5.2, SW6.2, U7.19 (ADC6)
/TXD: J2.5, U7.31 (PD1(TXD))
/TiNA_rtc/5V0: C1.1, C2.1, C16.2, C21.2, C22.2, C23.2, C24.1, C25.1, C26.1, J1.2, J2.3, J4.3, J6.1, J8.1, J10.1, J16.1, J17.1, P3.1, R1.1, R2.1, R3.1, R7.1, R8.2, R11.2, SP1.1, SW2.1, U1.3 (VIN), U1_Alt1.2, U2.14 (VCCB), U6.1 (VDD), U6_Alt1.1, U7.4 (VCC), U7.6 (VCC), U7.18 (AVCC), U7.20 (AREF); also elsewhere on the board
/TiNA_rtc/SCL: J6.2, J17.2, R1.2, U7.28 (PC5(ADC5/SCL)); also elsewhere on the board
/TiNA_rtc/SDA: J6.3, J17.3, R2.2, U7.27 (PC4(ADC4/SDA)); also elsewhere on the board
GND: C1.2, C2.2, C3.1, C5.2, C10.2, C11.2, C15.2, C16.1, C17.1, C21.1, C22.1, C23.1, C24.2, C25.2, C26.2, D1.2 (K), J1.6, J2.1, J2.2, J4.1, J5.1, J5.4, J5.5, J6.4, J8.2 (PM), J10.2 (PM), J16.2 (PM), J17.4, J18.1, P3.2, Q1.1 (E), R15.1, SD1.6, SD1.G1, SD1.G2, SD1.G3, SD1.G4, SW1.1, U1.1 (GND), U1_Alt1.1, U2.7 (GND), U3.2 (GND), U6.2 (VSS), U6_Alt1.2, U7.3 (GND), U7.5 (GND), U7.21 (AGND), X1.3; also elsewhere on the board
unnamed: C3.2, R3.2, U3.3 (Vs)
unnamed: C7.1, J2.6
unnamed: C8.2, U5.9 (SS/TR)
unnamed: C14.2, R6.2, R6.3
unnamed: C18.2, R10.2, R10.3
unnamed: D1.1 (A), R5.2
unnamed: L1.1, U5.1 (SW), U5.2 (SW), U5.3 (SW)
unnamed: Q1.2 (B), R16.2
unnamed: Q1.3 (C), SP1.2
unnamed: R4.1, U5.4 (PG)
unnamed: R11.1, R12.2, SW3.1
unnamed: R12.1, R13.2, SW4.1
unnamed: R13.1, R14.2, SW5.1
unnamed: R14.1, R15.2, SW6.1

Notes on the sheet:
IR SENSOR
BLINK D13
FTDI Header
ICSP Header
Mtg Holes
PWR INPUT (7V-17V DC or 5-12V AC)
Graphic Equalizer
SD-Card (Storage)
I2C Header's
MTG HOLE
Switches
TiM Interface

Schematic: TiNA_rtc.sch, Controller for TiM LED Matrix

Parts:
B2, B3, B15: I/O
BT1: BATT_RTC; CR2032; Digikey BU2032SM-HD-GCT-ND
C9: 100nF; c_0805
J3: rtcBOB/CD; rtcBOB
R9: 10k; r_0805
SL1: EN_RTC; ShortLink
U4: DS3231N; DS3231

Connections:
/TiNA_rtc/5V0: J3.7, SL1.2 (PM); also elsewhere on the board
/TiNA_rtc/32k: B15.1, J3.3, U4.1 (32KHz)
/TiNA_rtc/BAT: BT1.+, C9.1, J3.4, U4.14 (Vbat)
/TiNA_rtc/RST: B3.1, J3.1, U4.4 (!(Reset))
/TiNA_rtc/SCL: J3.6, U4.16 (SCL); also elsewhere on the board
/TiNA_rtc/SDA: J3.5, U4.15 (SDA); also elsewhere on the board
/TiNA_rtc/SQW: B2.1, J3.2, R9.2, U4.3 (!(INT)/SQR)
GND: BT1.-, C9.2, J3.8, U4.5 (NC), U4.6 (NC), U4.7 (NC), U4.8 (NC), U4.9 (NC), U4.10 (NC), U4.11 (NC), U4.12 (NC), U4.13 (GND); also elsewhere on the board
unnamed: R9.1, SL1.1, U4.2 (Vcc)

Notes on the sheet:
SMD headers for rtcBoB/ChronoDot

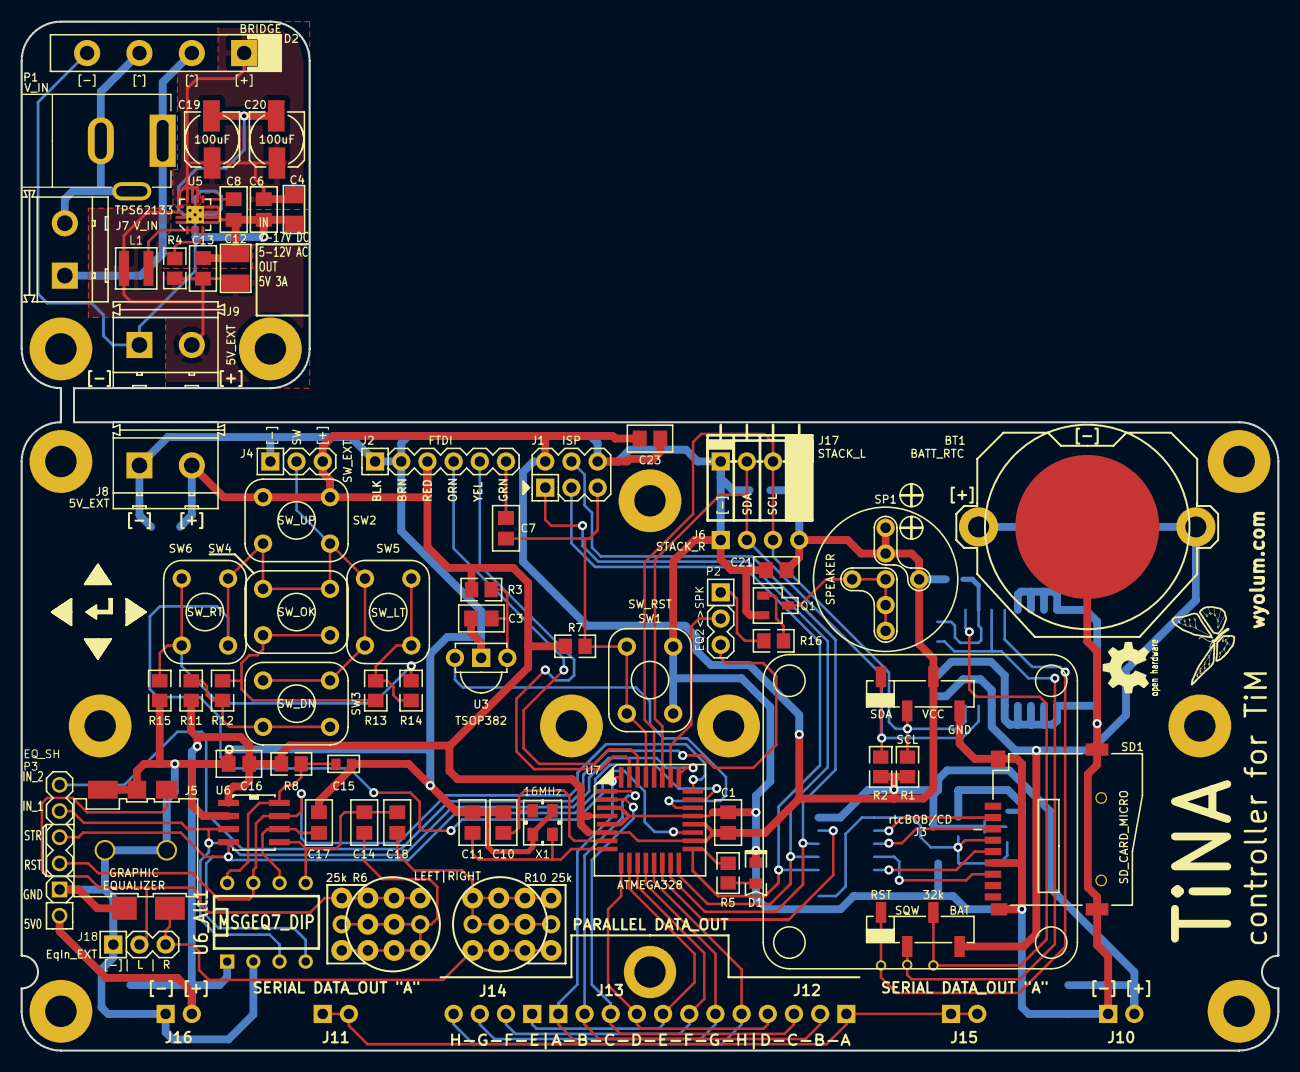
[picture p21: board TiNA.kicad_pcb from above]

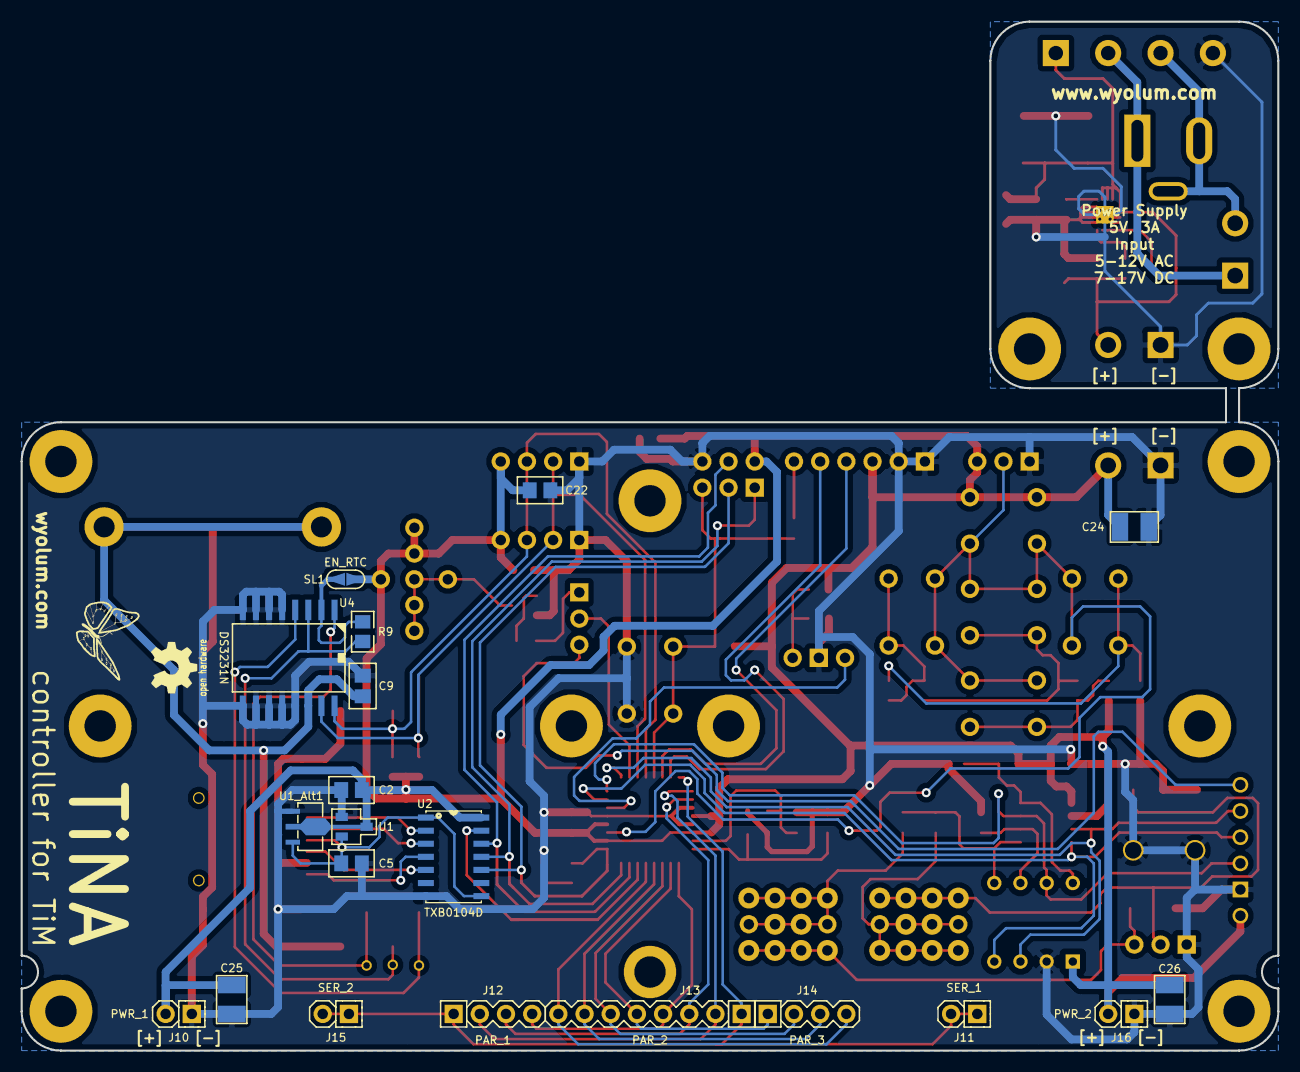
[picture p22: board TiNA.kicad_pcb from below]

Board: 2 copper layers, 121.9 x 99.8 mm, 104 parts (21 on the bottom side), 63 nets.

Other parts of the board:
G1, G1#2: Logo-WL3

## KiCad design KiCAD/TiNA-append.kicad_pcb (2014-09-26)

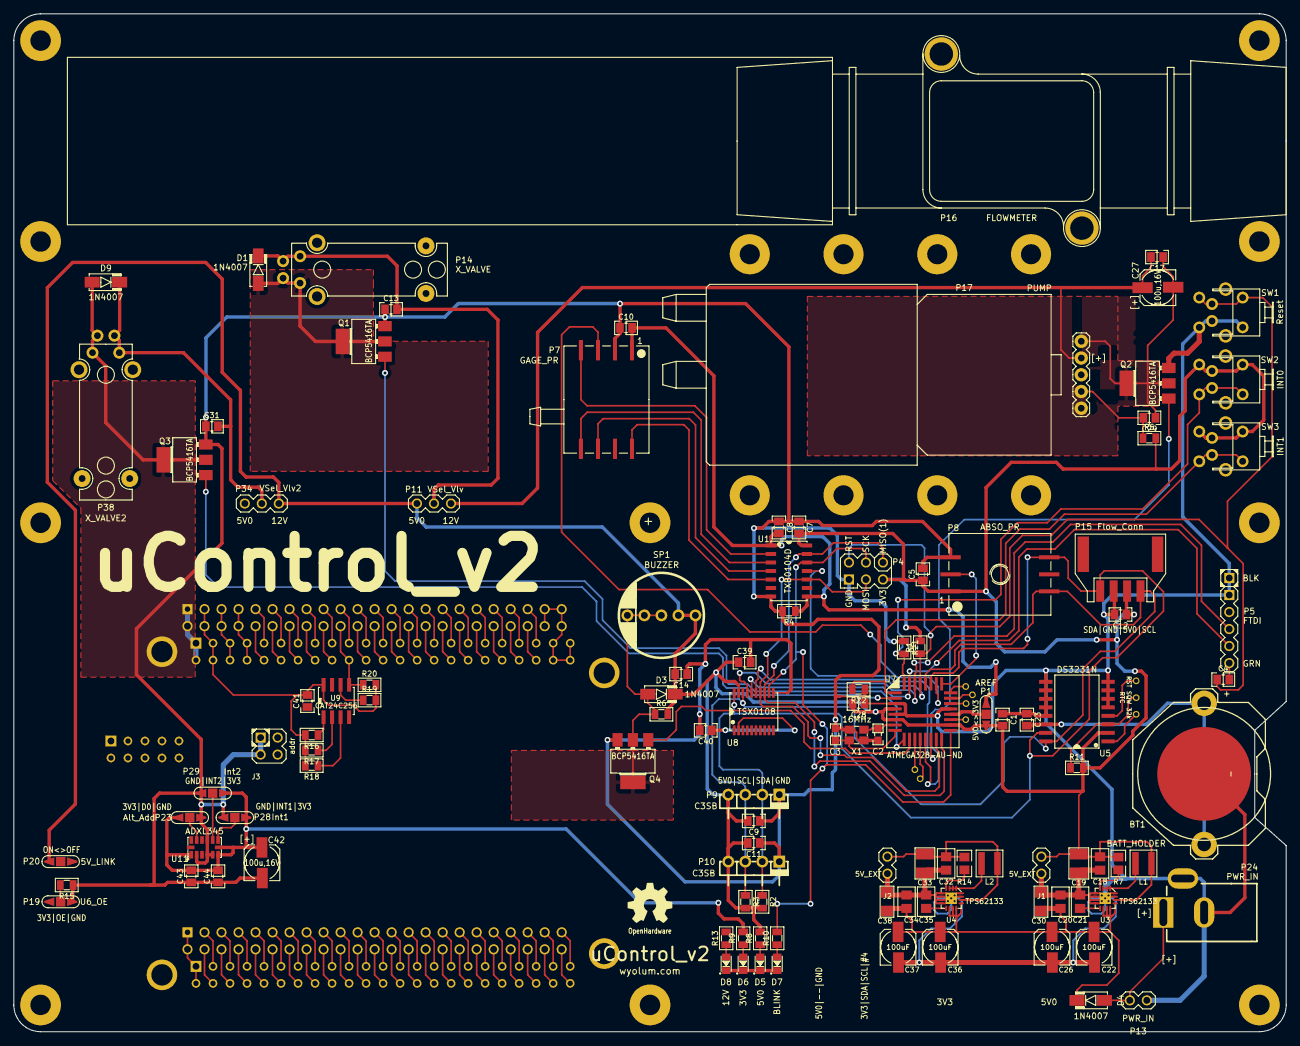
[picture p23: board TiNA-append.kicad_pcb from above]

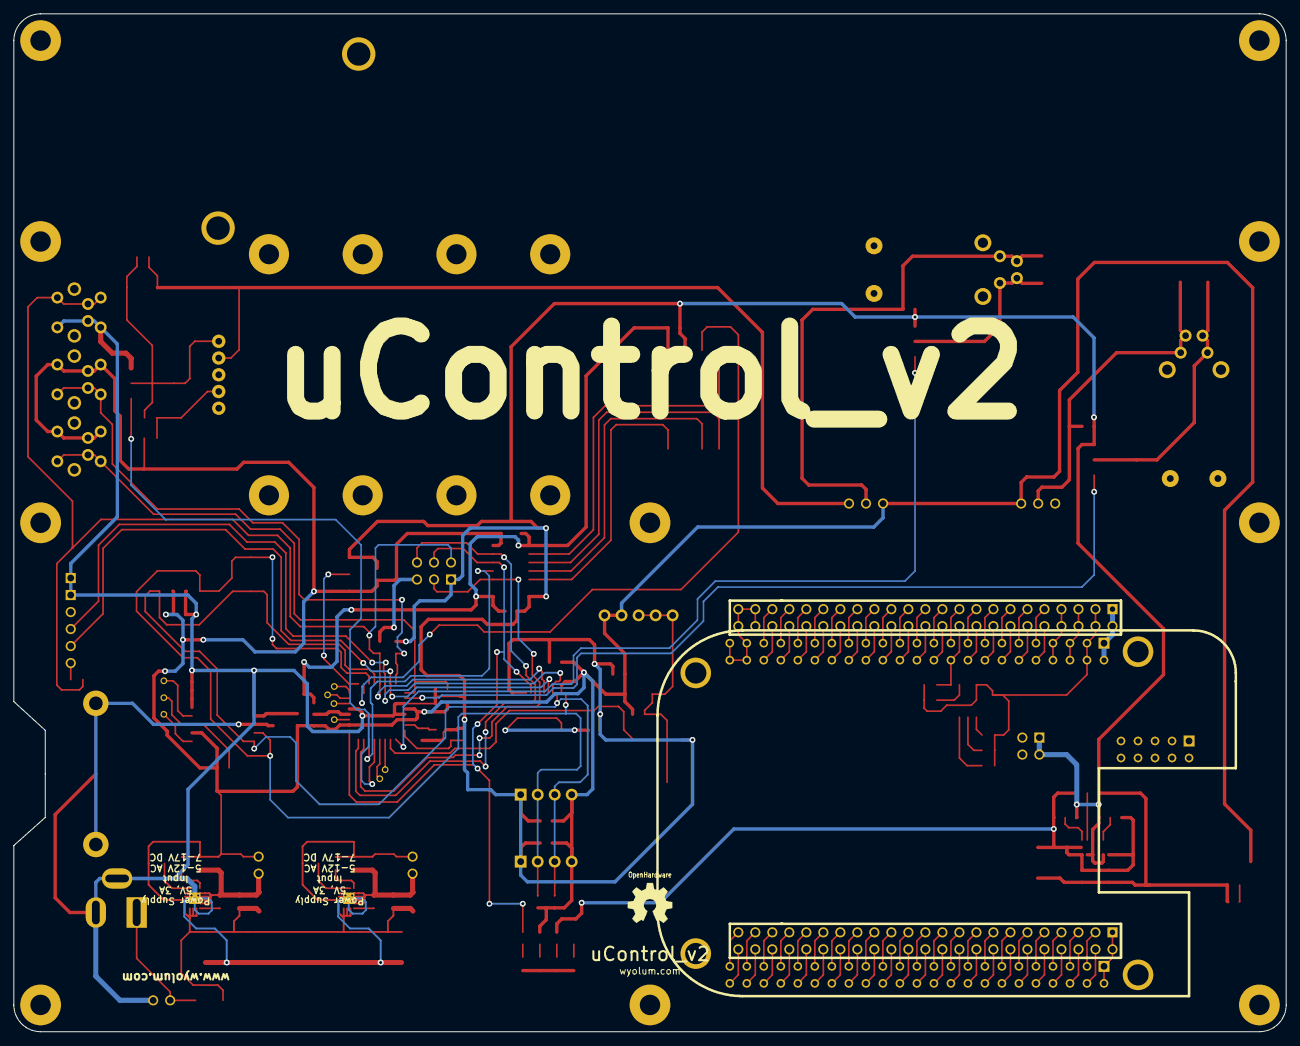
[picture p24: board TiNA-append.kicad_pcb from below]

Board: 2 copper layers, 190.0 x 152.0 mm, 137 parts (4 on the bottom side), 147 nets.

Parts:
B1, B2, B3: I_O
B4, B12: PB0; I_O
B8: PC0; I_O
B9: PC1; I_O
B10: PC6; I_O
B11: PC7; I_O
BT1: BATT_HOLDER; CR2032
C1, C4, C5, C7, C8, C9, C10, C11, C12, C13, C14, C17, C23, C28, C29, C31, C39, C40, C41, C43, C44: 100n; c_0805
C2, C3: 22p; c_0603
C18, C20, C32, C34: 100nF; c_0805
C19, C33: 22uF X7R; c_1210
C21, C35: 3.3nF; c_0805
C22, C26, C36, C37: 100uF; C_ELCO_SMD
C27, C42: 100u,16V; C_ELCO_SMD
C30, C38: 10uF X7R; c_1206
D1, D3, D4, D9: 1N4007; diode-DO214AC
D5: 5V0; led_0805
D6: 3V3; led_0805
D7: BLINK; led_0805
D8: 12V; led_0805
G3, G4: Logo_OH; OSHW_6mm
J1, J2: 5V_EXT; Header_2
J3: addr; Header_2x2
L1, L2: 2u2H,3.0A; Inductor_SMD3
P1: AREF; ShortLink2
P4: ICSP; Header_ISP
P5: FTDI; Header_FTDI
P7: GAGE_PR; HCEM500GUH9P3
P8: ABSO_PR; HDIB002AUY8H5
P9, P10: C3SB; pin_strip_4-90
P11: VSel_Vlv; Header_3
P13: PWR_IN; Header_2
P14: X_VALVE; X_Valve_2
P15: Flow_Conn; Conn_Flow_SFM3000_Male
P16: FLOWMETER; FlowMeter_CFM3000
P17: PUMP; Pump_P54E01R_02
P19: U6_OE; ShortLink2
P20: 5V_LINK; ShortLink2
P21, P22: CONN_23X2; PIN_ARRAY_23X2
P23: Alt_Add; ShortLink2
P24: PWR_IN; JACK_ALIM
P28: Int1; ShortLink2
P29: Int2; ShortLink2
P34: VSel_Vlv2; Header_3
P38: X_VALVE2; X_Valve_2
PCB1: PCB
Q1, Q2, Q3, Q4: BCP5416TA; SOT223
R1, R2, R3, R4, R11, R15, R21, R22: 10k; r_0805
R5: 4k7; r_0805
R6, R10, R13: 1k; r_0805
R7, R14: 100k; r_0805
R8: 330E; r_0805
R9: 120E; r_0805
R16, R17, R18: 4k75; r_0805
R19, R20: 1k5; r_0805
SC1, SC2, SC3, SC4, SC5, SC6, SC7, SC8, SC9, SC10: SCREW; vite_3mm
SP1: BUZZER; Speaker
SW1: Reset; SW_PB_V_H
SW2: INT0; SW_PB_V_H
SW3: INT1; SW_PB_V_H
U1: TXB0104D
U3, U4: TPS62133; TPS62132
U5: DS3231N; DS3231
U7: ATMEGA328-AU-ND; TQFP32
U8: TSX0108; TXS0108EPWR
U9: CAT24C256; SO8E
U10: BEAGLEBONE
U11: ADXL345
X1: 16MHz; Xtal_SMD3

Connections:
+3.3V: C8.1, C10.1, C32.2, C33.1, C42.1, C43.1, C44.1, J2.1, L2.2, P1.1, P7.1, P23.3, P28.3, P29.3, R4.2, R9.1, R14.2, U1.1, U1.8, U4.14, U11.1, U11.6, U11.7
/AREF: P1.2, U7.20
/BBB/5V0: C1.1, C5.2, C7.1, C9.1, C11.1, C12.2, C14.1, C18.2, C19.1, C28.1, C39.2, D3.2, J1.1, L1.2, P1.3, P4.2, P8.1, P9.1, P10.1, P11.1, P15.2, P20.1, P34.1, R1.1, R2.1, R3.1, R5.1, R6.1, R7.2, R8.1, R11.1, SP1.1, SW2.2, SW3.2, U1.14, U3.14, U5.2, U7.4, U7.6, U7.18, U8.19
/BBB/A0: J3.3, R16.2, U9.1
/BBB/A1: J3.1, R17.2, U9.2
/BBB/A2: R18.2, U9.3
/BBB/ACL_INT1: P28.2, U11.8
/BBB/ACL_INT2: P29.2, U11.9
/BBB/ACL_SDO: P23.2, U11.12
/BBB/AIN0: P21.39, U10.C39
/BBB/AIN1: P21.40, U10.C40
/BBB/AIN2: P21.37, U10.C37
/BBB/AIN3: P21.38, U10.C38
/BBB/AIN4: P21.33, U10.C33
/BBB/AIN5: P21.36, U10.C36
/BBB/AIN6: P21.35, U10.C35
/BBB/BBB_OE: P19.2, R15.1, U8.10
/BBB/CLKOUT2: P21.41, U10.C41
/BBB/DGND_8: P22.1, P22.2, U10.B1, U10.B2
/BBB/DGND_9_2: P21.43, P21.44, P21.45, P21.46, U10.C43, U10.C44, U10.C45, U10.C46
/BBB/EHRPWM1A: P21.14, U10.C14
/BBB/EHRPWM1B: P21.16, U10.C16
/BBB/EHRPWM2A: P22.19, U10.B19
/BBB/EHRPWM2B: P22.13, U10.B13
/BBB/GNDA_ADC: P21.34, U10.C34
/BBB/GPIO0_7: P21.42, U10.C42
/BBB/GPIO0_26: P22.14, U10.B14
/BBB/GPIO0_27: P22.17, U10.B17
/BBB/GPIO1_0: P22.25, U10.B25
/BBB/GPIO1_1: P22.24, U10.B24
/BBB/GPIO1_2: P22.5, U10.B5
/BBB/GPIO1_3: P22.6, U10.B6
/BBB/GPIO1_4: P22.23, U10.B23
/BBB/GPIO1_5: P22.22, U10.B22
/BBB/GPIO1_6: P22.3, U10.B3
/BBB/GPIO1_7: P22.4, U10.B4
/BBB/GPIO1_12: P22.12, U10.B12
/BBB/GPIO1_13: P22.11, U10.B11
/BBB/GPIO1_14: P22.16, U10.B16
/BBB/GPIO1_15: P22.15, U10.B15
/BBB/GPIO1_16: P21.15, U10.C15
/BBB/GPIO1_17: P21.23, U10.C23
/BBB/GPIO1_28: P21.12, U10.C12
/BBB/GPIO1_29: P22.26, U10.B26
/BBB/GPIO1_30: P22.21, U10.B21
/BBB/GPIO1_31: P22.20, U10.B20
/BBB/GPIO2_1: P22.18, U10.B18
/BBB/GPIO2_6: P22.45, U10.B45
/BBB/GPIO2_7: P22.46, U10.B46
/BBB/GPIO2_8: P22.43, U10.B43
/BBB/GPIO2_9: P22.44, U10.B44
/BBB/GPIO2_10: P22.41, U10.B41
/BBB/GPIO2_11: P22.42, U10.B42
/BBB/GPIO2_13: P22.40, U10.B40
/BBB/GPIO2_22: P22.27, U10.B27
/BBB/GPIO2_23: P22.29, U10.B29
/BBB/GPIO2_24: P22.28, U10.B28
/BBB/GPIO2_25: P22.30, U10.B30
/BBB/GPIO3_19: P21.27, U10.C27
/BBB/GPIO3_21: P21.25, U10.C25
/BBB/GPIO_12: P22.39, U10.B39
/BBB/I2C1_SCL: P21.17, U8.3, U10.C17, U11.14
/BBB/I2C1_SDA: P21.18, U8.1, U10.C18, U11.13
/BBB/I2C2_SCL: P21.19, R19.2, U9.6, U10.C19
/BBB/I2C2_SDA: P21.20, R20.2, U9.5, U10.C20
/BBB/MISO: P4.1, U1.13, U7.16, U8.13
/BBB/PWR_BUT: P21.9, U10.C9
/BBB/RESET: C4.2, P4.5, R1.2, SW1.2, U7.29, U8.15
/BBB/RXD: P5.4, U7.30, U8.17
/BBB/SCK: P4.3, R10.1, U1.12, U7.17, U8.12
/BBB/SCL: P8.6, P9.2, P10.2, P15.1, R3.2, U5.16, U7.28, U8.18
/BBB/SDA: P8.4, P9.3, P10.3, P15.4, R2.2, U5.15, U7.27, U8.20
/BBB/SPI1_CS0: P21.28, U10.C28
/BBB/SPI1_D0: P21.29, U8.8, U10.C29
/BBB/SPI1_D1: P21.30, U8.7, U10.C30
/BBB/SPI1_SCLK: P21.31, U8.9, U10.C31
/BBB/SYS_5V: P21.7, P21.8, U10.C7, U10.C8
/BBB/SYS_RESETn: P21.10, U10.C10
/BBB/TIMER4: P22.7, U10.B7
/BBB/TIMER5: P22.9, U10.B9
/BBB/TIMER6: P22.10, U10.B10
/BBB/TIMER7: P22.8, U10.B8
/BBB/TXD: P5.5, U7.31, U8.16
/BBB/UART1_RXD: P21.26, U8.5, U10.C26
/BBB/UART1_TXD: P21.24, U8.4, U10.C24
/BBB/UART2_RXD: P21.22, U10.C22
/BBB/UART2_TXD: P21.21, U10.C21
/BBB/UART3_CTSN: P22.36, U10.B36
/BBB/UART3_RTSN: P22.34, U10.B34
/BBB/UART4_CTSN: P22.35, U10.B35
/BBB/UART4_RTSN: P22.33, U10.B33
/BBB/UART4_RXD: P21.11, U10.C11
/BBB/UART4_TXD: P21.13, U10.C13
/BBB/UART5_CTSN: P22.31, U10.B31
/BBB/UART5_RTSN: P22.32, U10.B32
/BBB/UART5_RXD: P22.38, U10.B38
/BBB/UART5_TXD: P22.37, U10.B37
/BBB/VDD_3V3EXP: C40.2, C41.1, P19.1, P21.3, P21.4, R16.1, R17.1, R18.1, R19.1, R20.1, U8.2, U9.8, U10.C3, U10.C4
/BBB/VDD_5V: P20.2, P21.5, P21.6, U10.C5, U10.C6
/BBB/VDD_ADC: P21.32, U10.C32
/BBB/~MOSI: P4.4, U1.10, U7.15, U8.14
/Interface/12V: C17.1, C20.2, C22.1, C26.1, C27.1, C30.1, C34.2, C36.1, C37.1, C38.1, D4.2, P11.3, P17.2, P34.3, R13.1, U3.10, U3.11, U3.12, U3.13, U4.10, U4.11, U4.12, U4.13
/Interface/+Vlv: C13.1, D1.2, P11.2, P14.1
/Interface/+Vlv2: C31.1, D9.2, P34.2, P38.1
/Interface/-Vlv: D1.1, P14.2, Q1.2
/Interface/-Vlv2: D9.1, P38.2, Q3.2
/Interface/PC2_Pr2: P8.2, U7.25
/Interface/PC3_Pr1: P7.3, U7.26
/Interface/PD4_Valve2: Q3.1, U7.2
/Interface/P_MISO: P7.4, U1.2
/Interface/P_MOSI: P7.8, U1.5
/Interface/P_SCK: P7.5, U1.3
/Interface/P_SS: P7.6, U1.4
/Interface/Pump: C29.1, P17.4, R5.2
/Interface/Spk: D3.1, Q4.2, R6.2, SP1.2
/Interface/~PB1_Pump: Q2.1, U7.13
/Interface/~PD5_Valve: Q1.1, U7.9
/Interface/~PD6_Spk: Q4.1, U7.10
/Interface/~SS: U1.11, U7.14
/PB0: B12.1, U7.12
/PB6: C2.1, U7.7, X1.1
/PB7: C3.1, U7.8, X1.2
/PC0: B8.1, U7.23
/PC1: B9.1, U7.24
/PC6: B10.1, U7.19
/PC7: B11.1, U7.22
/PD2: R21.1, SW2.1, U7.32
/PD7: B4.1, U7.11
/pwr/PWR_IN: D4.1, P13.1, P24.1
/rtc/32k: B3.1, U5.1
/rtc/BAT: BT1.+, C23.1, U5.14
/rtc/RST: B2.1, U5.4
/rtc/SQR: B1.1, R11.2, U5.3
/~PD3: R22.1, SW3.1, U7.1
/~RTS: C4.1, P5.6
GND: BT1.-, C1.2, C2.2, C3.2, C5.1, C7.2, C8.2, C9.2, C10.2, C11.2, C12.1, C13.2, C14.2, C18.1, C19.2, C20.1, C21.1, C22.2, C23.2, C26.2, C28.2, C30.2, C31.2, C32.1, C33.2, C34.1, C35.1, C36.2, C37.2, C38.2, C39.1, C40.1, C41.2, C42.2, C43.2, C44.2, D5.2, D6.2, D7.2, D8.2, J1.2, J2.2, J3.2, J3.4, P4.6, P5.1, P5.2, P7.2, P8.3, P9.4, P10.4, P13.2, P15.3, P19.3, P21.1, P21.2, P23.1, P24.2, P24.3, P28.1, P29.1, Q1.3, Q2.3, Q3.3, Q4.3, R4.1, R15.2, R21.2, R22.2, SW1.1, U1.7, U3.5, U3.6, U3.7, U3.8, U3.15, U3.16, U4.5, U4.6, U4.7, U4.8, U4.15, U4.16, U5.5, U5.6, U5.7, U5.8, U5.9, U5.10, U5.11, U5.12, U5.13, U7.3, U7.5, U7.21, U8.11, U9.4, U10.C1, U10.C2, U11.2, U11.4, U11.5, U11.10, X1.3
unnamed: C21.2, U3.9
unnamed: L1.1, U3.1, U3.2, U3.3
unnamed: R7.1, U3.4
unnamed: D7.1, R10.2
unnamed: D8.1, R13.2
unnamed: D6.1, R9.2
unnamed: D5.1, R8.2
unnamed: C35.2, U4.9
unnamed: L2.1, U4.1, U4.2, U4.3
unnamed: R14.1, U4.4
unnamed: C17.2, C27.2, C29.2, P17.1, Q2.2

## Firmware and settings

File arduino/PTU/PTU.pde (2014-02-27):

// HERE!
#include "rtcBOB.h"
#include "Time.h"
#include "Wire.h"

#include "Arduino.h"
#include "SoftwareSerial.h"

#include <TinyGPS++.h>
#include <EEPROM.h>

#define DEFINED

volatile unsigned long count = 0;
volatile unsigned long pps_start_us = 0;
volatile unsigned long pps_tick_us = 1000000;  // filtered
volatile unsigned long _pps_tick_us = 1000000; // unfiltered

volatile unsigned long rtc_start_us = 0;          
volatile unsigned long rtc_tick_us = 1000000;  // filtered
volatile unsigned long _rtc_tick_us = 1000000; // unfiltered

unsigned long sync_time = 0;     // seconds of last GPS 1pps sync
unsigned long last_set_time = 0; // seconds of last GPS time set

// drift = actual_us - desired_us
// drift > 0 ==> pulse is late
// drift < 0 ==> pulse is early
volatile          long rtc_drift_us;          // Filtered


volatile boolean pps_led_state = true;
volatile boolean sqw_led_state = true;
volatile boolean synced = false;

const int SQW_PIN = 3;
const int PPS_PIN = 2;
const int  PPS_LED = 7;
const int  SQW_LED = 4;
const unsigned int RTC_STALE_S = 1800;
const unsigned int RTC_SECOND_STALE_S = 1000 * 3600;// 1000 hours
const unsigned long  RTC_WRITE_US = 1750;
const unsigned long OFFSET_US = 1000;
const uint8_t chipSelect = 10;
const unsigned long DELTA_TOL = 5000;

void pps_interrupt(){
  unsigned long  now_us = micros();
  _pps_tick_us = (now_us - pps_start_us);
  pps_led_state = !pps_led_state;
  digitalWrite(PPS_LED, pps_led_state);
  pps_start_us = now_us;
}

void rtc_interrupt(){
  unsigned long  now_us = micros();
  long drift_us;
  // Serial.println("rtc_interrupt");
  sqw_led_state = !sqw_led_state;
  digitalWrite(SQW_LED, sqw_led_state);
  rtc_start_us = now_us;
}

bool save_sync_time(){
  uint8_t len = 14;

  char dat[len];
  dat[1] = len;
  Time_to_Serial(sync_time, dat + 2);
  Time_to_Serial(last_set_time, dat + 6);
  ulong_to_Serial(pps_tick_us, dat + 10); 
  ulong_to_Serial(rtc_tick_us, dat + 14);
}

bool restore_sync_time(){
  bool out;
  uint8_t len = 14;
  char dat2[len];

  if(out){
    sync_time = Serial_to_time(dat2 + 2);
    last_set_time = Serial_to_time(dat2 + 4);
  }
  return out;
}

// write 4 bytes of in into char buffer out.
void Time_to_Serial(time_t in, char *out){
  time_t *out_p = (time_t *)out;
  *out_p = in;
}

time_t Serial_to_time(char *in){
  time_t out;
  out = *(time_t *)in;
  return out;
}

// write 4 bytes of in into char buffer out.
void ulong_to_Serial(unsigned long in, char *out){
  unsigned long *out_p = (unsigned long *)out;
  *out_p = in;
}
unsigned long Serial_to_ulong(char *in){
  unsigned long out;
  out = *(unsigned long *)in;
  return out;
}

static const int RXPin = 6, TXPin = A7;
static const uint32_t GPSBaud = 9600;

// The TinyGPS++ object
TinyGPSPlus gps;

// The serial connection to the GPS device
SoftwareSerial sws(RXPin, TXPin);

void setup()
{
  Serial.begin(115200);
  sws.begin(GPSBaud);

  Serial.begin(115200);
  Serial.println("Precision Timing Unit v1.0");
  Serial.println("Copyright WyoLum, LLC, 2014");
  
  Wire.begin();
  rtc_set1Hz();
  
  // From MaceTech.com: set 1Hz reference square wave
  Wire.beginTransmission(0x68); // address DS3231
  WIRE_WRITE1(0x0E); // select register
  WIRE_WRITE1(0b00000000); // write register bitmap, bit 7 is /EOSC
  Wire.endTransmission();

  pinMode(PPS_LED, OUTPUT);
  pinMode(SQW_LED, OUTPUT);

  pinMode(PPS_PIN, INPUT);
  pinMode(SQW_PIN, INPUT);

  digitalWrite(PPS_LED, HIGH);
  digitalWrite(SQW_LED, HIGH);

  delay(100);
  digitalWrite(PPS_LED, LOW);
  digitalWrite(SQW_LED, LOW);

  set_1Hz_ref(getTime(), SQW_PIN, rtc_interrupt, FALLING);
  Serial.println("Waiting for 1Hz signal");
  while(rtc_start_us == 0){
    delay(100);
  }
  Serial.println("1Hz signal present");
  attachInterrupt(PPS_PIN - 2, pps_interrupt, RISING);
  smartDelay(1000);
  if(micros() - pps_start_us < 2e6){
    Serial.println("1pps signal present.");
  }
  else{
    Serial.println("NO 1pps signal present");
  }
  
  Serial.print("micros() - pps_start_us: ");
  Serial.println(micros() - pps_start_us);

  setRTC(2010, 1, 1, 0, 0, 0); // DBG!!! TODO:

  initialize_clock();

  Serial.print("now():");
  Serial.println(now());

  Serial.println("initialization done.");
}

void initialize_clock(){

  if((year() < 2011 or year() > 2040)){ // first acq
    Serial.print("Year:");
    Serial.print(year());
    Serial.println("< 2011");
    sws.begin(9600);
    while(year() < 2011){
      smartDelay(1000);
      Serial.print("gps.time.age(): ");
      Serial.println(gps.time.age());
      if (gps.time.isValid() && 
	  (gps.time.age() < 1000)){
	// (micros() - (pps_start_us < 1e6))){
	setRTC(gps.date.year(), 
	       gps.date.month(),
	       gps.date.day(), 
	       gps.time.hour(), 
	       gps.time.minute(), 
	       gps.time.second());
	Serial.println(year());
	setTime(getTime());
      }
      Serial.print(gps.date.year());
      Serial.print(" ");
      Serial.print(gps.time.isValid());
      Serial.print(" ");
      Serial.print(year());
      Serial.print(" ");
      Serial.println(gps.date.age());
    }
    sws.end();
    attachInterrupt(SQW_PIN - 2, pps_interrupt, RISING);
    Serial.print("new year:");
    Serial.println(year());
  } // expect YMD HM to be current beyond here.
  seconds_sync();
  fine_sync();
}

// assumes HHMMDD HHMM are correct
void seconds_sync(){
  unsigned long start_s;
  if(now() - last_set_time > RTC_SECOND_STALE_S){
    sws.begin(9600);
    pause_1Hz();
    start_s = now();

    // wait for next second boundary
    while(now() == start_s){
      smartDelay(0);
    }
    sws.end();
    unpause_1Hz();
    last_set_time = now();
    save_sync_time();
  }
}

// assumes YY/MM/DD are accurate
/*
 * TJS: If RTC is not stale, do nothing.  Otherwise do fine sync with GPS.
 */
void fine_sync(){
  boolean out = false;
  unsigned long now_s;
  unsigned long target_us;
  unsigned long delta_us;
  int sec_frac;
  
  if((micros() - pps_start_us) < 2 * pps_tick_us){ // fine sync available
    Serial.println("Fine sync available");
    if(pps_start_us > rtc_start_us){
      delta_us = pps_start_us - rtc_start_us;
    }
    else{
      delta_us = rtc_start_us - pps_start_us;
    }
    // sync if time is stale and we have a GPS signal
    if((now() - sync_time > RTC_STALE_S && (micros() - pps_start_us) < 2 * pps_tick_us) || 
       delta_us > DELTA_TOL){
      Serial.println("fine_sync()");
      Serial.print(now());
      Serial.print("-");
      Serial.print(sync_time);
      Serial.print(" ");
      Serial.println(now() - sync_time);
      now_s = now();
      Serial.println("Time stale");

      // have YYMMDD hhmmss, now synchronize pulses
      // 1. let tick times settle
      for(int i = 0; i < 3; i++){
	wait_for_next_gps_second();
	Serial.println("gps tick()");
      }
      target_us = 0;
      while(target_us < pps_start_us){ // watch for integer overflow
	// 2. wait for start of next second
	wait_for_next_gps_second();
	target_us = pps_start_us + pps_tick_us;
      }
      // 3. compute next second
      now_s = now();
      sec_frac = millisecond();
      if(sec_frac > 500){
	now_s++;
      }
    
      // 3. pause clock
      pause_1Hz();

      // 4. wait for expected next rtc pulse
      // RTC_WRITE_US is the time it takes to set clock
      // OFFSET_US is to keep the interrupts from colliding.
      while(micros() < target_us - RTC_WRITE_US + OFFSET_US){
      }
      setRTC(now_s + 1);

      // 5. unpause 1Hz
      unpause_1Hz();

      // 6 check sync
      for(int i = 0; i < 3; i++){
	wait_for_next_gps_second();
	Serial.println("gps tick()");
      }
      sqw_led_state = !pps_led_state;
      Serial.print("SYNC RESULT:");
      Serial.print(rtc_start_us);
      Serial.print(", ");
      Serial.print(pps_start_us);
      Serial.print(", ");
      if(pps_start_us < rtc_start_us){
	Serial.println(rtc_start_us - pps_start_us);
      }
      else{
	Serial.print("-");
	Serial.println(pps_start_us - rtc_start_us);
      }
      sync_time = now();
      save_sync_time();
    }
  }
  else{
    Serial.println("Fine sync NOT available");
  }
}

void wait_for_next_rtc_second(){
  while(digitalRead(SQW_PIN) == LOW){}
  while(digitalRead(SQW_PIN) == HIGH){}
}
void wait_for_next_gps_second(){
  while(digitalRead(PPS_PIN) == HIGH){}
  while(digitalRead(PPS_PIN) == LOW){}
}

void grab_datetime(unsigned long _date, 
		   unsigned long _time,
		   long lat,
		   long lon,
		   long alt,
		   unsigned long speed,
		   unsigned long course){
  int YY, MM, DD, hh, mm, ss;
  unsigned long date = _date;
  unsigned long time = _time;
  hh = time / 1000000;
  time = time % 1000000;
  mm = time / 10000;
  time = time % 10000;
  ss = time / 100;
  setRTC(year(), month(), day(), hh, mm, ss);
  setTime(getTime());
  // Serial.print("LAT:");
  // Serial.println(lat / 1e5);
  // Serial.print("LON:");
  // Serial.println(lon / 1e5);
  if(date > 0){
    DD = date / 10000;
    date = date % 10000;
    MM = date / 100; 
    date = date % 100;
    YY = 2000 + date;
    setRTC(YY, MM, DD, hour(), minute(), second());
  }

  last_set_time = getTime();
  setTime(last_set_time);

#ifdef NOT_DEFINED
  Serial.print("YY");
  Serial.println(YY);
  Serial.print("year():");
  Serial.println(year());
  Serial.print(_date);
  Serial.print(",");
  Serial.print(_time);
  Serial.print("  ");
  Serial.print(YY);
  Serial.print("/");
  Serial.print(MM);
  Serial.print("/");
  Serial.print(DD);
  Serial.print(" ");
  Serial.print(hh);
  Serial.print(":");
  Serial.print(mm);
  Serial.print(":");
  Serial.print(ss);
  Serial.println();
  setRTC(year(), month(), day(), hour(), minute(), second());
  Serial.print(YY);
  Serial.print("/");
  Serial.print(MM);
  Serial.print("/");
  Serial.println(DD);
#endif
}

void loop(){
  Serial.print("loop() ");
  Serial.print(rtc_start_us);
  Serial.print(", ");
  Serial.print(pps_start_us);
  Serial.print(", ");
  if(pps_start_us < rtc_start_us){
    Serial.print(rtc_start_us - pps_start_us);
    if((rtc_start_us - pps_start_us) < 2000){
      // good to go
    }
    else{
      // resync
    }
  }
  else{
    Serial.print("-");
    Serial.print(pps_start_us - rtc_start_us);
  }
  rtc_setAgingOffset(count++ / 8 %256 - 128);
  Serial.print(", aging offset:");
  Serial.print(rtc_getAgingOffset());
  
  Serial.print(" uS offset, ");
  Serial.print(year());
  Serial.print("/");
  Serial.print(month());
  Serial.print("/");
  Serial.print(day());
  Serial.print(" ");
  Serial.print(hour());
  Serial.print(":");
  Serial.print(minute());
  Serial.print(":");
  Serial.print(second());
  Serial.println();

  // fine_sync();
  delay(2000);
}

void do_nothing(){
}
bool feedgps()
{
  while (sws.available())
  {
    char c = sws.read();
    // Serial.print(c);
    if (gps.encode(c))
      return true;
  }
  return false;
}

void printFloat(double number, int digits)
{
  // Handle negative numbers
  if (number < 0.0)
  {
     Serial.print('-');
     number = -number;
  }

  // Round correctly so that print(1.999, 2) prints as "2.00"
  double rounding = 0.5;
  for (uint8_t i=0; i<digits; ++i)
    rounding /= 10.0;
  
  number += rounding;

  // Extract the integer part of the number and print it
  unsigned long int_part = (unsigned long)number;
  double remainder = number - (double)int_part;
  Serial.print(int_part);

  // Print the decimal point, but only if there are digits beyond
  if (digits > 0)
    Serial.print("."); 

  // Extract digits from the remainder one at a time
  while (digits-- > 0)
  {
    remainder *= 10.0;
    int toPrint = int(remainder);
    Serial.print(toPrint);
    remainder -= toPrint; 
  } 
}
// This custom version of delay() ensures that the gps object
// is being "fed".
static void smartDelay(unsigned long ms)
{
  unsigned long start = millis();
  do 
  {
    while (sws.available())
      gps.encode(sws.read());
  } while (millis() - start < ms);
}

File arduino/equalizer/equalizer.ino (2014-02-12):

#include "Adafruit_NeoPixel.h"

const uint8_t pins[8] = {9, 8, 7, 6, 5, 4, 3, 2};
const uint8_t N_STRIP = 8;

Adafruit_NeoPixel strips[8];

// eq stuff
const int strobe = A0; // strobe pins on digital 4
const int res = A1; // reset pins on digital 5


int eqLevels[7]; // store band values in these arrays


void setup(){
  Serial.begin(115200);
   pinMode(res, OUTPUT); // reset
  pinMode(strobe, OUTPUT); // strobe
  

  for(uint8_t i = 0; i < N_STRIP; i++){
  // all strips share the same buffer
    strips[i].setup(16, pins[i], NEO_GRB + NEO_KHZ800);
    strips[i].begin();
    strips[i].show();
    pinMode(pins[i],OUTPUT);
    digitalWrite(pins[i],LOW);
  }
  clearAll();
  InitMSGEq7();
}

int pixel =0;
int row =0;

void loop(){
  clearAll();
  InitMSGEq7();
  readMSGEQ7();
  for (int i=0; i < 7; i++){
      int level = map(eqLevels[i],0,600,0,16);
      setBar(i,level);
    }
    showall();
    delay(10);
}

void showall(){
  for (int i = 0; i < N_STRIP; i++){
    strips[i].changed = true;
    strips[i].show();
  }
}
// Fill the dots one after the other with a color
void colorFill(uint8_t strip, uint32_t c) {
  for(uint16_t i=0; i<strips[strip].numPixels(); i++) {
      strips[strip].setPixelColor(i, c);
  }
}
void clearAll(){
   for(int row =0;row < N_STRIP; row++){
       for(uint16_t i=0; i<strips[row].numPixels(); i++) {
          strips[row].setPixelColor(i, 0);
       }
   }
}
void setBar(uint8_t row, uint8_t level)
{
   uint32_t color;

  for(uint16_t i=0; i < level; i++) {
     if (i <= 4 )
       color = Color(0,127,0); // green
     else if (i > 4 && i < 10)
       color = Color(80,80,0);
     else
       color = Color(127,0,0);
     strips[row].setPixelColor(i, color);
  }
}
uint32_t Color(uint8_t red, uint8_t green, uint8_t blue){
  return strips[0].Color(red,green,blue);
}
// Example 48.1 - tronixstuff.com/tutorials > chapter 48 - 30 Jan 2013 
// MSGEQ7 spectrum analyser shield - basic demonstration

int band;
int EQ_OUT1 = A2;
void InitMSGEq7()
{
 digitalWrite(res,LOW); // reset low
 digitalWrite(strobe,HIGH); //pin 5 is RESET on the shield
}
void readMSGEQ7()
// Function to read 7 band equalizers
{
 digitalWrite(res, HIGH);
 digitalWrite(res, LOW);
 for(band=0; band <7; band++)
 {
 digitalWrite(strobe,LOW); // strobe pin on the shield - kicks the IC up to the next band 
 delayMicroseconds(30); // 
 eqLevels[band] = analogRead(EQ_OUT1); // store left band reading
 digitalWrite(strobe,HIGH); 
 }
 dumpEQ();
}

void dumpEQ(){

// display values of right channel on serial monitor
 for (band = 0; band < 7; band++)
 {
 Serial.print(eqLevels[band]);
 Serial.print(" ");
 }
 Serial.println();
 
}


  

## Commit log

2014-02-07 modified buttonTest for new 1M Ohm pull down on SW
2014-02-15 added a fabrication directory and files
    [cornercube.scad]
2014-02-15 added tabs to prevent roll up
    [cornercube.scad]
2014-02-17 made edge piece for cornercube.scad
    [cornercube.scad]
2014-02-19 started button interface. added python serial interface
    [$button_bar.sch, button_bar.kicad_pcb, button_bar.sch]
2014-02-21 merged Anool's mods
    [$button_bar.sch, button_bar.kicad_pcb, button_bar.sch]
2014-02-21 move filter cap to connect to ground
    [button_bar.sch]
2014-02-21 added tracks, moved to new directory
    [button_bar.kicad_pcb, button_bar.sch]
2014-02-21 redo tracks
    [button_bar.kicad_pcb]
2014-02-21 finished tracks on ButtonBar
    [button_bar.kicad_pcb]
2014-02-21 switched PMU to TinyGPS++
2014-02-21 button board pcb update ajm
    [button_bar.kicad_pcb, button_bar.sch, button_bar_jts.kicad_pcb]
2014-02-27 working on PTU glitches
    [cornercube.scad]
2014-03-03 added button box laser cut drawing
2014-03-04 squared reset button bar
2014-05-17 I added a couple of colors and changed the countdown time earlier today. just copied that one over to the TiNA folder
2014-09-26 added KiCad design files for TiNA
    [BoM_TiNA.ods, BoM_TiNA.xls, BoM_TiNA_pcb.csv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]
